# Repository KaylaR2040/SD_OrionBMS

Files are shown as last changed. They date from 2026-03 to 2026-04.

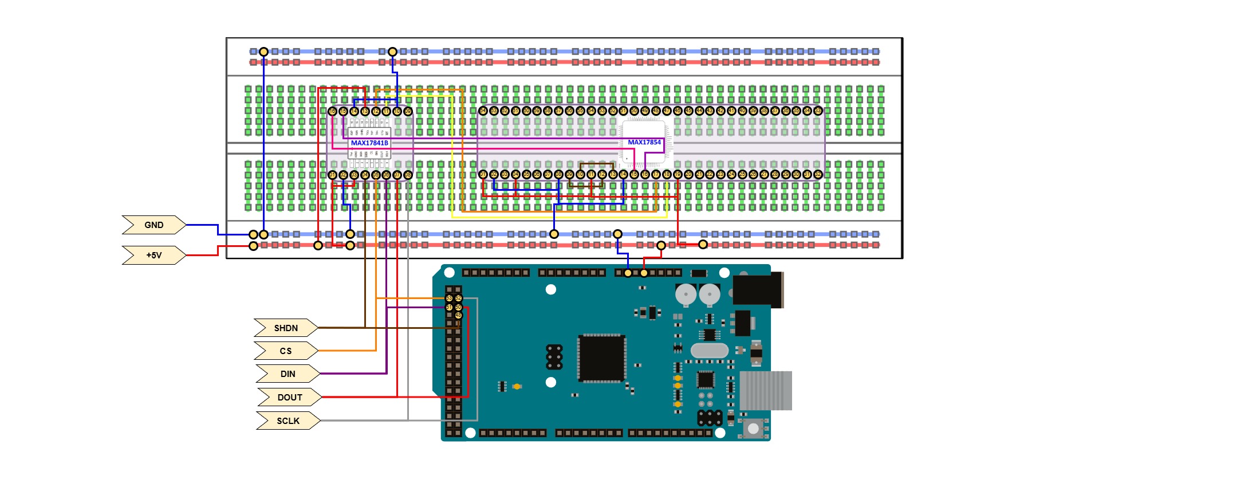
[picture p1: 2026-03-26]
Docs/SPI_ADC_BREADBOARD.jpg

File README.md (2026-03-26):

# EV Active Sensor Adapter

A compact, HV-aware sensing module for an FSAE EV accumulator. It acquires per-cell voltages and thermistor temperatures, validates each sample batch, and publishes telemetry on Classical CAN for the logger/BMS. The firmware uses an RTOS framework with timer-triggered ADC + DMA, deterministic validation/packetization, and an isolated CAN transceiver. The repository is structured so any developer can rebuild, verify, and extend the system quickly.

---

## Table of Contents
- [Project Purpose](#project-purpose)
- [Core Functionality](#core-functionality)
- [System Architecture](#system-architecture)
- [RTOS Design (Actors & IPC)](#rtos-design-actors--ipc)
- [Repository Structure](#repository-structure)
- [Build & Run](#build--run)
- [Configuration](#configuration)
- [Data & CAN](#data--can)
- [Documentation (Doxygen)](#documentation-doxygen)
- [File/Library Origins & Licenses](#filelibrary-origins--licenses)
- [Issue Tracking & Versioning](#issue-tracking--versioning)
- [Keywords / SEO](#keywords--seo)
- [Target Audience](#target-audience)
- [Roadmap](#roadmap)
- [Acknowledgments](#acknowledgments)

---

## Project Purpose
Design and validate a pass-through “active sensor adapter” that reads per-cell voltages and thermistors and relays them to the team’s logger/BMS over CAN. The goals are to minimize wiring and board count, meet the accumulator envelope and safety requirements, and keep the system straightforward to integrate and debug during scrutineering.

## Core Functionality
- **Acquisition:** Differential cell-tap sensing per segment; scaling to MCU ADC range (0–3.3 V) via analog front-end; thermistor sense and linearization.
- **Validation:** Range checks, monotonicity/slew checks, optional moving average/median filtering; configurable limits.
- **Publication:** Periodic CAN frames with per-cell voltages, temperatures, and health flags; heartbeat and diagnostics frames.
- **Timing:** ADC triggered by hardware timer; DMA → processing → CAN TX within fixed RTOS time budgets.
- **Safety & EMC:** Isolated CAN PHY; partitioned HV/LV domains; input protection and layout rules for creepage/clearance.

---

## System Architecture
**High level**
```
[Cell Taps & Thermistors] → [Analog Front-End] → [MCU ADC + DMA] 
    → [RTOS Tasks: Validate, Packetize] → [CAN Controller] → [Isolated CAN Transceiver] → [Logger / BMS]
```

**Major blocks**
- **Analog Front-End:** Differential measurement per cell segment; scale/offset to ADC domain; RC anti-alias/filtering; ESD/OVP where applicable.
- **MCU + Firmware:** ADC + DMA; timer-driven sampling; RTOS tasks for validation/packing; CAN driver; non-volatile config.
- **CAN Subsystem:** On-chip CAN controller (Classical CAN; 11/29-bit); isolated transceiver; configurable bitrate and filters.

---

## RTOS Design (Actors & IPC)
| Actor (Type) | Purpose | Period / Trigger | IPC / Resources |
|---|---|---|---|
| `adc_sampler` (ISR/DMA CB)| Kick conversions; DMA completion handling | Timer @ e.g., 100–200 Hz  | Queue → `validate_task` |
| `validate_task` (task) | Range/slew checks; filtering | On queue receive | Queue → `can_tx_task` |
| `can_tx_task` (task) | Pack frames; rate-limit; send via CAN | On queue / 10–50 Hz slots | CAN driver; TX mailbox |
| `diag_task` (task) | Heartbeat; error counters; self-tests | 1 Hz | CAN driver |
| `config_task` (task) | Apply params from NVM/debug console | On command | NVM / CLI / UART (optional)|

IPC: queues for sample batches, mutex for config access, event flags for errors/heartbeat, semaphore for CAN TX credit.  
RTOS: FreeRTOS or CMSIS-RTOS2 shim. The framework is present even if minimal features are used.

---

## Repository Structure
```
.
├─ firmware/
│  ├─ app/
│  │  ├─ main.c
│  │  ├─ tasks_can.c
│  │  ├─ tasks_validate.c
│  │  ├─ tasks_diag.c
│  │  └─ app_config.h
│  ├─ drivers/
│  │  ├─ adc_drv.c/.h
│  │  ├─ can_drv.c/.h
│  │  ├─ timer_drv.c/.h
│  │  └─ board_pins.h
│  ├─ rtos/
│  │  ├─ rtos_port.c/.h         # CMSIS-RTOS2 or FreeRTOS glue
│  │  └─ freertos/              # (if vendored; else via submodule)
│  ├─ utils/
│  │  ├─ filters.c/.h
│  │  ├─ crc.c/.h
│  │  └─ log.c/.h
│  └─ CMakeLists.txt / *.project (if CCS)
├─ hardware/
│  ├─ schematics/
│  └─ pcb/
├─ dbc/
│  └─ ev_active_sensor.dbc
├─ tools/
│  ├─ can_dump_example.py
│  └─ dbc_gen.py
├─ docs/
│  ├─ doxygen/
│  │  └─ Doxyfile
│  └─ images/
├─ LICENSE
└─ README.md
```

---

## Build & Run

You can recreate the system using one of the paths below. All code elements should build directly in GitHub CI and locally.

### Option A: TI Code Composer Studio (CCS)
1. Install CCS and the vendor SDK/driver pack for TMS320F23897xD.
2. `File → Import… → Existing CCS Project`, select `firmware/`.
3. Select the correct target and connection.
4. Build and flash. Use the “Release” profile for timing-accurate tests.

### Option B: CMake + ARM GCC (or vendor GCC)
```bash
cd firmware
cmake -B build -DCMAKE_TOOLCHAIN_FILE=toolchains/arm-none-eabi.cmake -DMCU=<TMS320F23897x>
cmake --build build -j
# Flash with preferred programmer, e.g.:
# openocd -f interface/<probe>.cfg -f target/TMS320F23897x.cfg -c "program build/firmware.elf verify reset exit"
```

### Bring-up checklist
- Confirm ADC reference and pin mapping in `board_pins.h` and `app_config.h`.
- Set CAN bitrate/filters in `app_config.h` (500 kbps, 1megps).
- Connect isolated CAN transceiver to the vehicle bus; verify TX/RX loopback on bench first.
- Start the logger; verify heartbeat and telemetry frames appear at the expected rates.

---

## Configuration
Edit `app_config.h` (or use CLI/UART if enabled):
- `SAMPLE_RATE_HZ`, `CAN_BITRATE`, `FRAME_PERIOD_MS`
- Channel enable masks; number of cells; thermistor Beta constants
- DBC frame IDs and scaling

---

## Data & CAN
- **CAN Type:** Classical CAN (11-bit or 29-bit).
- **Frames:**
  - `CELL_VOLTAGES_n`: packed per-cell voltages (scaled in mV)
  - `CELL_TEMPS_n`: packed temperatures (0.1 °C or °C)

---

## Documentation (Doxygen)
- In-code comments follow Doxygen style; functions link back to project requirements via `@req EV-REQ-###`.
- Generate docs locally:
  ```bash
  doxygen docs/doxygen/Doxyfile
  ```
- Publish: upload `docs/html/` via GitHub Pages or attach as a CI artifact.

---

## File/Library Origins & Licenses
- **Our code:** `firmware/app`, `firmware/utils`, and project glue — Apache-2.0 (see `LICENSE`).
- **RTOS:** FreeRTOS (MIT) via submodule or vendor package; see submodule `LICENSE`.
- **Drivers:** Either written in-house (Apache-2.0) or vendor HAL (vendor license). Each file header states origin and license.
- **DBC & tools:** Team-authored, Apache-2.0 unless otherwise noted.

> Every third-party directory includes a `NOTICE` with origin URL, version, and license.

---

## Issue Tracking & Versioning
- Use GitHub Issues for bugs/features. Each issue should include: owner, date, code version (git SHA), description, and resolution.
- Commits must include *what changed and why* in the message body.
- Releases are tagged (`vMAJOR.MINOR.PATCH`), with one marked **Final** for hand-off at semester end.

---

## Keywords / SEO
FSAE EV, battery monitoring, cell voltage sensing, thermistor sensing, differential measurement, ADC DMA, Classical CAN, isolated CAN transceiver, RTOS, FreeRTOS, CMSIS-RTOS2, embedded firmware, automotive EMC, accumulator.

## Target Audience
FSAE teams, embedded/firmware students, and engineers building HV-aware sensing for battery telemetry.

---

## Roadmap
- [ ] Bench characterization: ADC INL/DNL, noise, and filter step response
- [ ] Fault injection: wire-off, short, out-of-range, thermistor open/short
- [ ] CAN filter/ID finalization with logger/BMS DBC
- [ ] Production test mode & golden-frame generator
- [ ] CI: static analysis and unit tests for filters and validators

---

## Acknowledgments
Thanks to faculty mentors, the electrical subteam, and sponsors supporting test equipment and PCB fab.

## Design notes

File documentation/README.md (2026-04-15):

# SD Orion BMS Documentation

This folder is the maintainable documentation set for the STM32G474-based Orion thermistor and battery-monitor interface firmware in this repository.

Content is derived from active source (`src/`, `include/`, `platformio.ini`) and checked-in project docs/vendor references in `Docs/`.

## Who this is for

- New engineers bringing up a fresh board or MCU
- Firmware developers navigating architecture and modules
- Debug/operations engineers handling flashing, boot, logging, CAN, and battery-monitor issues

## What this documentation covers

- Fast onboarding and first flash
- Hardware setup and signal/pin mapping
- Firmware architecture and code map
- Communication behavior (USART2 logs, USART1 BQ transport, FDCAN)
- Troubleshooting, known issues, and bring-up recovery
- Chip inventory and board component references

## Start here

1. `getting_started.md`
2. `hardware_setup.md`
3. `pinout_and_signals.md`
4. `startup_and_flashing.md`

Then continue with:

- `system_overview.md`
- `firmware_overview.md`
- `code_map.md`
- `communication.md`

For debugging:

- `logging_and_leds.md`
- `troubleshooting.md`
- `known_issues_and_resolutions.md`
- `bringup_checklist.md`

Reference and component details:

- `reference/hardware_reference.md`
- `reference/firmware_reference.md`
- `reference/toolchain_and_programmer_reference.md`
- `reference/chip_inventory.md`

## Critical bring-up note

For this project, first-time MCU bring-up must include STM32CubeProgrammer option-byte review and reset/debug configuration before trusting normal flashing/debug behavior. See `startup_and_flashing.md`.

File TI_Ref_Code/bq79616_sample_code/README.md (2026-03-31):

# BQ79616-Q1 Sample Code for TMS570LS1224 (LAUNCH XL2)
This repository contains the BQ79616-Q1 sample code for the TMS570LS1224. This includes many useful functions that can be used for future development for the BQ79616-Q1.
## Pinout
CONNECTIONS BETWEEN BQ79616EVM AND LAUNCH XL2 (TMS570LS1224): 

* bq79616EVM J17 pin 1 (NC)     -> FLOAT
* bq79616EVM J17 pin 2 (NC)     -> FLOAT
* bq79616EVM J17 pin 3 (NFAULT) -> LAUNCH XL2 J4 pin 10 (PA0)
* bq79616EVM J17 pin 4 (NC)     -> FLOAT
* bq79616EVM J17 pin 5 (GND)    -> LAUNCH XL2 J3 pin 2  (GND)
* bq79616EVM J17 pin 6 (3V3)    -> LAUNCH XL2 J2 pin 1  (3V3)
* bq79616EVM J17 pin 7 (RX)     -> LAUNCH XL2 J2 pin 4  (UATX)
* bq79616EVM J17 pin 8 (TX)     -> LAUNCH XL2 J2 pin 3  (UARX)
* bq79616EVM J17 pin 9 (NC)     -> FLOAT
* bq79616EVM J17 pin 10 (NC)    -> FLOAT

RELEVANT MODIFIED FILES:

* bq79616.h        must change TOTALBOARDS and MAXBYTES here for code to function
* bq79616.c        contains all relevant functions used in the sample code
* notification.c   sets UART_RX_RDY and RTI_TIMEOUT when their respective interrupts happen
* .dil/.hcg        used for generating the basic TMS570LS1224 code files, can be used to make changes to the microcontroller

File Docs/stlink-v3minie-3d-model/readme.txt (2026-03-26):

******************************************************************************
* @file    readme.txt
* @author  GPAM Application Team
* @version 1.0
* @date    28-March-2025
* @brief   STLINK-V3MINIE 3D model
******************************************************************************
* COPYRIGHT(c) 2025 STMicroelectronics
*
* The Open Platform License Agreement (“Agreement”) is a binding legal contract
* between you ("You") and STMicroelectronics International N.V. (“ST”), a
* company incorporated under the laws of the Netherlands acting for the purpose
* of this Agreement through its Swiss branch 39, Chemin du Champ des Filles,
* 1228 Plan-les-Ouates, Geneva, Switzerland.
*
* By using the enclosed reference designs, schematics, PC board layouts, and
* documentation, in hardcopy or CAD tool file format (collectively, the
* “Reference Material”), You are agreeing to be bound by the terms and
* conditions of this Agreement. Do not use the Reference Material until You
* have read and agreed to this Agreement terms and conditions. The use of
* the Reference Material automatically implies the acceptance of the Agreement
* terms and conditions.
*
* The complete Open Platform License Agreement can be found on www.st.com/opla.
******************************************************************************

========================
* 1.0 - 28-March-2025
========================
    + First official release.
  
******************* (C) COPYRIGHT 2025 STMicroelectronics *****END OF FILE

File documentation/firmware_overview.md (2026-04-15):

# Firmware Overview

## Runtime architecture

The firmware is organized as a simple service loop with timer-driven scheduling flags:

- Main loop (`src/main.c`):
  - `Therm_ServiceTask()`
  - `CAN_ServiceTask()`
  - `Volt_ServiceTask()`

- System startup (`src/init.c`):
  - HAL/clocks/GPIO/LED
  - UART init (STLINK + BQ)
  - ADC + CAN + timers
  - blocking BQ bring-up state gate

## Startup sequence

`System_AppInit()` executes this order:

1. `HAL_Init()`
2. `SystemClock_Config()`
3. `LED_Init()`
4. `clocks_configure_all()`
5. `UART_Stlink_Init()` (USART2)
6. `UART_BQ79616_Init()` (USART1)
7. `Therm_App_Init()`
8. `CAN_App_Init(1000 kbps)`
9. `Timers_Init()`
10. `Volt_RunBlockingStartup()`
11. Release CAN scheduling based on BQ state

## Major modules and responsibilities

- `src/therm.c`: ADC1 channel sampling, thermistor snapshot logging
- `src/thermistor_table.c`: ADC-to-temperature conversion
- `src/can.c`: FDCAN init/transport and service entry
- `src/can_messages.c`: message encoding, fault handling, transmission scheduling hooks
- `src/bq79616.c`: wake, keep-alive, fault polling, cell reads
- `src/volt.c`: BQ state machine wrapper and degraded-mode behavior
- `src/timer.c`: TIM6/TIM7 scheduling and staggered log flags
- `src/uart.c`: logging layer and BQ UART transport handles

## Firmware data flow

1. Therm ADC values captured into `g_can_ctx.thermistors`.
2. Temperature/fault cache computed.
3. BQ task updates external voltage buffer into `g_can_ctx.voltages`.
4. CAN task packages and sends periodic frames.
5. UART logging and LEDs expose state transitions/failures.

## Init/loop/driver relationships

- Initialization is centralized in `System_AppInit()`.
- Driver and protocol code stay in dedicated modules.
- ISRs stay short; periodic work is done in service tasks in non-ISR context.

See also:

- `code_map.md`
- `communication.md`
- `diagrams/startup_flowchart.md`

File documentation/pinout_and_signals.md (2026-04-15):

# Pinout and Signals

This is the consolidated pin and interface map for bring-up/debug, derived from active code first and then cross-checked against existing project notes.

## Source-of-truth priority

1. Active code in `src/` and `include/`
2. Board/vendor docs in `Docs/`
3. Older notes only when they agree with code

## MCU pin map used by current firmware

### UART

| Function | Peripheral | MCU Pin | Source |
|---|---|---|---|
| Log TX | USART2 TX | `PA2` | `src/uart.c`, `src/stm32g4xx_hal_msp.c` |
| Log RX | USART2 RX | `PA3` | `src/uart.c`, `src/stm32g4xx_hal_msp.c` |
| BQ TX | USART1 TX | `PC4` | `src/uart.c`, `src/stm32g4xx_hal_msp.c` |
| BQ RX | USART1 RX | `PC5` | `src/uart.c`, `src/stm32g4xx_hal_msp.c` |

### CAN

| Function | Peripheral | MCU Pin | Source |
|---|---|---|---|
| CAN RX | FDCAN1 RX | `PA11` | `src/stm32g4xx_hal_msp.c` |
| CAN TX | FDCAN1 TX | `PA12` | `src/stm32g4xx_hal_msp.c` |

### ADC thermistor channels

| Therm Channel | ADC Channel | MCU Pin | Source |
|---|---|---|---|
| 1 | ADC1_IN1 | `PA0` | `src/therm.c` |
| 2 | ADC1_IN2 | `PA1` | `src/therm.c` |
| 3 | ADC1_IN11 | `PB12` | `src/therm.c` |
| 4 | ADC1_IN14 | `PB11` | `src/therm.c` |
| 5 | ADC1_IN5 | `PB14` | `src/therm.c` |
| 6 | ADC1_IN6 | `PC0` | `src/therm.c` |
| 7 | ADC1_IN7 | `PC1` | `src/therm.c` |
| 8 | ADC1_IN8 | `PC2` | `src/therm.c` |
| 9 | ADC1_IN9 | `PC3` | `src/therm.c` |
| 10 | ADC1_IN15 | `PB0` | `src/therm.c` |

### LEDs

| LED | MCU Pin | Source |
|---|---|---|
| LED1 | `PA9` | `include/main.h` |
| LED2 | `PA8` | `include/main.h` |
| LED3 | `PC9` | `include/main.h` |

## SWD / programming signals

The firmware docs assume standard SWD wiring is present and stable:

- SWDIO
- SWCLK
- NRST
- GND
- VREF

Project bring-up requirement:

- Use **NRST Level 3** in programmer setup for reliable flashing/debug behavior in this project.

See `startup_and_flashing.md`.

## Known pinout note conflict in older docs

`Docs/PINOUT.md` contains a logging UART mapping that references LPUART1/AF12 on `PA2/PA3`, while active code configures USART2/AF7 for logging. Current firmware source (`src/uart.c`, `src/stm32g4xx_hal_msp.c`) is the authoritative mapping.

## Quick bench validation

1. Confirm UART logs at `115200` over STLINK VCP.
2. Confirm CAN traffic on FDCAN1 (`PA11`/`PA12`).
3. Confirm therm channels produce changing ADC values in logs.
4. Confirm BQ transport path uses `PC4`/`PC5` at `1000000` baud.

See also:

- `hardware_setup.md`
- `communication.md`
- `logging_and_leds.md`
- `reference/chip_inventory.md`

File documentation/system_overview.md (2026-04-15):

# System Overview

## What this project does

This firmware runs on STM32G474 and publishes battery/thermal telemetry to CAN. It:

- Samples up to 10 thermistor channels on MCU ADC1
- Talks to a BQ79616 battery monitor chain over USART1
- Publishes Orion-style thermistor and external-voltage CAN frames over FDCAN1
- Emits debug/status logs over STLINK VCP (USART2)

## Main system components

- STM32G474 firmware core (`src/main.c`, `src/init.c`)
- Thermistor acquisition path (`src/therm.c`, `src/thermistor_table.c`)
- BQ79616 interface path (`src/bq79616.c`, `src/volt.c`)
- CAN transport and message packing (`src/can.c`, `src/can_messages.c`)
- Timing/scheduling (`src/timer.c`)

## High-level data flow

1. ADC samples thermistors.
2. Temperatures/fault masks are computed.
3. BQ path keeps comms alive and reads external cell voltages.
4. CAN scheduler transmits claim, BMS summary, general thermistor frames, and external-voltage segments.
5. Logs and LEDs expose runtime state.

See diagram: `diagrams/system_block_diagram.md`

## Startup/connection overview

- `System_AppInit()` initializes clocks, GPIO, UARTs, ADC, CAN, and timers.
- Startup blocks in BQ bring-up (`Volt_RunBlockingStartup()`), then CAN scheduling is released.
- If BQ fails, thermistor/CAN path still runs in degraded fault-reporting mode.

See diagram: `diagrams/startup_flowchart.md`

## Inputs and outputs

Inputs:

- Thermistor analog channels (ADC1)
- BQ UART response data
- Power/reset/debug configuration state

Outputs:

- UART logs on USART2 at 115200
- CAN frames on FDCAN1 at 1 Mbps default
- LED status indication for subsystem failures

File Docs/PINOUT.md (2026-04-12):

# Pin Assignments - STM32G474RET6
> Last Updated 4/12/26

Single consolidated map, grouped by peripheral/function. AF values match the HAL MSP setup in `src/stm32g4xx_hal_msp.c`.

| Group | Signal / Use | Pin | Pin # | AF / Mode | External Connection / Notes |
|---|---|---|---|---|---|
| UART | USART1 TX (BQ79616) | PC4 | 24 | AF7 USART1 | Connect to BQ79616-Q1 RX (Pin 52) |
| UART | USART1 RX (BQ79616) | PC5 | 25 | AF7 USART1 | Connect to BQ79616-Q1 TX (Pin 53) |
| UART | LPUART1 TX (logging) | PA2 | 14 | AF12 LPUART1 | Connect to ST-LINK `T_VCP_TX` (USB logging) |
| UART | LPUART1 RX (logging) | PA3 | 17 | AF12 LPUART1 | Connect to ST-LINK `T_VCP_RX` (USB logging) |
| CAN | FDCAN1 RX | PA11 | 46 | AF9 FDCAN1 | 1 Mbps default |
| CAN | FDCAN1 TX | PA12 | 47 | AF9 FDCAN1 | 1 Mbps default |
| SPI | SPI1 SCK | PA5 | 19 | AF5 SPI1 | MAX17841B / ASCI |
| SPI | SPI1 MISO | PA6 | 20 | AF5 SPI1 |  |
| SPI | SPI1 MOSI | PA7 | 21 | AF5 SPI1 |  |
| SPI | SPI1 CS (software) | PA4 | 18 | GPIO output | MAX17841B chip select (manual) |
| LED | LED1 | PA9 | 43 | GPIO output | Active high |
| LED | LED2 | PA8 | 42 | GPIO output | Active high |
| LED | LED3 | PC9 | 41 | GPIO output | Active high |
| GPIO | Spare | PC6 | 37 | GPIO | Unused |
| GPIO | Spare / analog header | PB15 | 36 | GPIO/Analog | Unused |
| GPIO | Spare / analog header | PB13 | 34 | GPIO/Analog | Unused |
| ADC1 | IN1 (Thermistor 1) | PA0 | 12 | Analog | ADC_CHANNEL_1 |
| ADC1 | IN2 (Thermistor 2) | PA1 | 13 | Analog | ADC_CHANNEL_2 |
| ADC1 | IN11 (Thermistor 3) | PB12 | 35 | Analog | ADC_CHANNEL_11 |
| ADC1 | IN14 (Thermistor 4) | PB11 | 33 | Analog | ADC_CHANNEL_14 |
| ADC1 | IN5 (Thermistor 5) | PB14 | 36 | Analog | ADC_CHANNEL_5 |
| ADC1 | IN6 (Thermistor 6) | PC0 | 8 | Analog | ADC_CHANNEL_6 |
| ADC1 | IN7 (Thermistor 7) | PC1 | 9 | Analog | ADC_CHANNEL_7 |
| ADC1 | IN8 (Thermistor 8) | PC2 | 10 | Analog | ADC_CHANNEL_8 |
| ADC1 | IN9 (Thermistor 9) | PC3 | 11 | Analog | ADC_CHANNEL_9 |
| ADC1 | IN15 (Thermistor 10) | PB0 | 23 | Analog | ADC_CHANNEL_15 |

## Notes
- BQ79616 runs on USART1 (PC4/PC5). Logging defaults to LPUART1 (PA2/PA3) to keep pins separated.
- PA4 is the software CS for MAX17841B (SPI1).
- All LEDs are active high; LED5 is the fault indicator.
- No DMA is used; UARTs/SPI are blocking for bring-up.
- BQ79616 datasheet reference: https://www.ti.com/lit/ds/symlink/bq79612-q1.pdf

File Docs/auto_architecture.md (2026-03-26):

# EV Active Sensor Adapter - Firmware System Architecture

## System Overview

```mermaid
flowchart LR
    subgraph SCHED["Execution and Scheduling"]
        direction TB
        BOOT["Boot and Init"]
        TICK["1ms Timebase"]
        LOOP["Main Service Loop"]
        BOOT --> TICK --> LOOP
    end

    subgraph VOLT["Voltage Lane"]
        direction TB
        V_IN["Cell Taps x14"]
        V_AFE["Analog Front-End"]
        V_ADC["External HV ADC"]
        V_TRS["UART TO SPI TRANSLATOR"]
        V_SPI["SPI Driver"]
        V_PROC["Voltage Processing"]
        V_IN --> V_AFE --> V_ADC <--> V_TRS <-->V_SPI --> V_PROC
    end

    subgraph TEMP["Temperature Lane"]
        direction TB
        T_IN["Thermistors x10"]
        T_ADC["STM32 ADC"]
        T_CONV["Lookup Table Conversion"]
        T_PROC["Temp Processing"]
        T_IN --> T_ADC --> T_CONV --> T_PROC
    end

    subgraph MODEL["Data Model"]
        direction TB
        BUF["Measurement Buffers"]
        META["Timestamps"]
        FAULTS["Fault State"]
        BUF --- META
        META --- FAULTS
    end

    subgraph FRAME["Message Assembly"]
        direction TB
        PACK["Frame Builder"]
        CRC["Checksum"]
        RATE["Rate Control"]
        PACK --> CRC --> RATE
    end

    subgraph CANNET["CAN Transport"]
        direction TB
        CAN_API["CAN API"]
        CAN_HAL["FDCAN HAL"]
        BUS["CAN Bus"]
        CAN_API --> CAN_HAL --> BUS
        BUS --> CAN_HAL --> CAN_API
    end

    subgraph DBG["Debug Interface"]
        direction TB
        LEDS["Status LEDs"]
        UART["UART Console"]
    end

    subgraph CONSUMERS["External Consumers"]
        direction TB
        BMS["Orion BMS"]
        LOGGER["Data Logger"]
    end

    LOOP --> V_SPI
    LOOP --> T_ADC
    V_PROC --> BUF
    T_PROC --> BUF
    BUF --> PACK
    META --> PACK
    FAULTS --> PACK
    RATE --> CAN_API
    CAN_API --> LEDS
    CAN_API --> UART
    FAULTS --> LEDS
    FAULTS --> UART
    BUS --> BMS
    BUS --> LOGGER
```

## Timing Constraints

```mermaid
flowchart TB
    subgraph TIMING["Message Timing Requirements"]
        direction LR
        T1["J1939 Address Claim"]
        T2["BMS Broadcast"]
        T3["General Broadcast"]
        T4["ADC Sampling"]
        T5["SPI Polling"]
    end

    T1 --- PERIOD1["200 ms period"]
    T2 --- PERIOD2["100 ms period"]
    T3 --- PERIOD3["100 ms period, round-robin"]
    T4 --- PERIOD4["Configurable, typical 100 ms"]
    T5 --- PERIOD5["Configurable, typical 200 ms"]
```

## Data Flow Detail

```mermaid
flowchart TB
    subgraph ADC_ACQUIRE["ADC Acquisition"]
        ADC_TASK["ADC_ServiceTask()"]
        ADC_SAMPLE["Sample 10 channels"]
        ADC_RAW["Raw ADC counts 0-4095"]
    end

    subgraph CONVERT["Temperature Conversion"]
        LOOKUP["Lookup Table"]
        CLAMP["Clamp to int8 range"]
        TEMPS["s_temps array"]
    end

    subgraph ENCODE["CAN Encoding"]
        BMS_ENC["EncodeBMSBroadcast()"]
        GEN_ENC["EncodeGeneralBroadcast()"]
        PAYLOAD["8-byte payload"]
    end

    subgraph TRANSMIT["CAN Transmit"]
        SEND_EXT["CAN_Comm_SendExt()"]
        FDCAN["FDCAN Peripheral"]
        WIRE["Physical Bus"]
    end

    ADC_TASK --> ADC_SAMPLE --> ADC_RAW
    ADC_RAW --> LOOKUP --> CLAMP --> TEMPS
    TEMPS --> BMS_ENC --> PAYLOAD
    TEMPS --> GEN_ENC --> PAYLOAD
    PAYLOAD --> SEND_EXT --> FDCAN --> WIRE
```

## Module Responsibilities

| Module | File | Purpose | Timing |
|---|---|---|---|
| Main | main.c | Init and main loop | Continuous |
| ADC | adc.c | Sample thermistor channels | Periodic |
| SPI | spi.c | Poll MAX17841 for cell data | Periodic |
| Thermistor | thermistor_table.c | ADC to temperature lookup | On demand |
| CAN Messages | can_messages.c | Encode BMS and General frames | On demand |
| CAN Core | can.c | FDCAN init, send, receive | Periodic |
| Timer | timer.c | HAL_GetTick based timing | 1 ms tick |
| Log | log.c | UART debug output | On demand |
| LED | led.c | Status indication | Periodic |
| Error | error_handling.c | Fault handling | On event |

## CAN Message Schedule

| Message | CAN ID | Period | Payload |
|---|---|---|---|
| J1939 Address Claim | 0x18EEFF80 | 200 ms | 8 bytes fixed |
| BMS Broadcast | 0x1839F380 | 100 ms | Module summary |
| General Broadcast | 0x183BF380 | 100 ms | Single thermistor, round-robin |

## Temperature Data Path

```mermaid
flowchart LR
    THERM["Thermistor"] --> DIVIDER["Voltage Divider"] --> PIN["ADC Pin"]
    PIN --> SAMPLE["ADC Sample"] --> COUNT["0-4095 count"]
    COUNT --> TABLE["Lookup Table"] --> SIGNED["int8_t temp"]
    SIGNED --> CAST["cast to uint8_t"] --> WIRE["CAN payload byte"]
    WIRE --> BMS["Orion BMS interprets as int8_t"]
```

## Initialization Sequence

```mermaid
flowchart TB
    START["Power On"] --> HAL["HAL_Init()"]
    HAL --> CLK["SystemClock_Config()"]
    CLK --> GPIO["GPIO_App_Init()"]
    GPIO --> UART["UART_Log_Init()"]
    UART --> ADC["ADC_App_Init()"]
    ADC --> SPI["SPI_App_Init()"]
    SPI --> CAN["CAN_App_Init()"]
    CAN --> LED["LED_Init()"]
    LED --> LOOP["Enter Main Loop"]
```

## Main Loop Execution

```mermaid
flowchart TB
    LOOP["Main Loop Start"] --> CHECK_ADC{"ADC period elapsed?"}
    CHECK_ADC -- yes --> RUN_ADC["ADC_ServiceTask()"]
    CHECK_ADC -- no --> CHECK_SPI
    RUN_ADC --> CHECK_SPI{"SPI period elapsed?"}
    CHECK_SPI -- yes --> RUN_SPI["SPI_ServiceTask()"]
    CHECK_SPI -- no --> CHECK_CAN
    RUN_SPI --> CHECK_CAN{"CAN period elapsed?"}
    CHECK_CAN -- yes --> RUN_CAN["CAN_ServiceTask()"]
    CHECK_CAN -- no --> LOOP
    RUN_CAN --> LOOP
```

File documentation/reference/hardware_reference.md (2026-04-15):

# Hardware Reference

Compact hardware facts extracted from active source and checked-in documentation.

## MCU and firmware target context

- Target MCU family: STM32G474 (`platformio.ini`, `STM32G474xx`)
- PlatformIO board env: `nucleo_g474re`
- Firmware uses HAL and selected LL modules

## Active pin/interface mappings from code

- UART logging: USART2 `PA2` TX / `PA3` RX (`src/uart.c`, `src/stm32g4xx_hal_msp.c`)
- BQ UART transport: USART1 `PC4` TX / `PC5` RX (`src/uart.c`, `src/stm32g4xx_hal_msp.c`)
- CAN: FDCAN1 `PA11` RX / `PA12` TX (`src/stm32g4xx_hal_msp.c`)
- Thermistor ADC channels (10): `PA0`, `PA1`, `PB12`, `PB11`, `PB14`, `PC0`, `PC1`, `PC2`, `PC3`, `PB0` (`src/therm.c`)
- LEDs: `PA9`, `PA8`, `PC9` (`include/main.h`)

For full signal tables, use `../pinout_and_signals.md`.

## Power and probe notes

- STLINK-V3MINIE supports debug/program and VCP.
- Checked-in ST docs (`Docs/um2910-*.pdf`) state STLINK-V3MINIE does not provide target application power.
- Use external target power for bring-up and runtime testing.

## Boot/reset bring-up notes (project)

- First-time bring-up requires option-byte review in CubeProgrammer.
- Project requires NRST Level 3 during setup/flashing for reliable behavior.
- Treat NRST Level 3 as project-specific unless validated otherwise on your hardware revision.

## Chip/component scope notes

- Active firmware path clearly uses STM32G474 + BQ79616.
- Additional component docs (for example ISO1050, MAX17841/MAX17854) are present in `Docs/` and should be verified against actual board population/BOM before use.

For complete component status, use `chip_inventory.md`.

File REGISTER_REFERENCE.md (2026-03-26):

/*
 * ===========================================================================
 * BQ79616 WAKE-UP SEQUENCE: REGISTER GUIDE
 * ===========================================================================
 *
 * This explains which registers are involved in waking up the BQ79616 from
 * SHUTDOWN mode and what they do.
 *
 * ===========================================================================
 * OVERVIEW OF DEVICE POWER STATES
 * ===========================================================================
 *
 * The BQ79616 has two main power modes:
 *
 * 1. SHUTDOWN MODE (Default after power-up)
 *    ├─ Minimal current draw
 *    ├─ No analog power to battery monitoring circuits
 *    ├─ No UART communications possible
 *    └─ Woken by: Two TX-low pulses on UART RXD line
 *
 * 2. ACTIVE MODE (After successful wake)
 *    ├─ Full power to analog circuits
 *    ├─ UART communication enabled
 *    ├─ Battery monitoring active
 *    └─ Returns to SHUTDOWN after timeout (if enabled)
 *
 *
 * ===========================================================================
 * REGISTER: CONTROL1 (Address 0x0001)
 * ===========================================================================
 *
 * This is the KEY register for wake control!
 *
 * BIT LAYOUT:
 * ───────────────────────────────────────────────────────────────────
 * BIT#  | NAME              | PURPOSE
 * ───────────────────────────────────────────────────────────────────
 *  7-6  | (reserved)        | Must be 0
 *  5    | SEND_WAKE         | ← THIS WAKES STACKED DEVICES
 *  4-2  | (reserved)        | Must be 0
 *  1-0  | (reserved)        | Must be 0
 * ───────────────────────────────────────────────────────────────────
 *
 * SEND_WAKE BIT (Bit 5):
 * ├─ Write 1: Device sends wake signal down the stack
 * ├─ Write 0: Normal operation
 * └─ Used in: bq79616_stack_single_init()
 *
 * YOUR CODE SENDS:
 * ────────────────
 *   uint8_t control1 = BQ_CONTROL1_SEND_WAKE_MASK;  // 0x20 = 0b0010_0000
 *   bq79616_write(0u, BQ_REG_CONTROL1_ADDR, &control1, 1u);
 *
 * This sets SEND_WAKE=1 which tells the bridge to pass the wake signal to
 * any stacked BQ79616 devices below it.
 *
 *
 * ===========================================================================
 * REGISTER: STATUS (Address 0x0000) - READ ONLY
 * ===========================================================================
 *
 * This tells you what mode the device is currently in.
 *
 * BIT LAYOUT (typical):
 * ─────────────────────────────────────────────────────
 * BIT#  | NAME                    | MEANING
 * ─────────────────────────────────────────────────────
 *  7    | No Cell Detected        | If 1: No cells detected
 *  6    | Cell Balance Mode       | If 1: Cell balancing active
 *  5    | Thermistor Mode         | If 1: Thermistor connected
 *  4    | ACTIVE                  | If 1: Device is ACTIVE ← CHECK THIS
 *  3    | (other)                 |
 *  2    | (other)                 |
 *  1    | (other)                 |
 *  0    | (other)                 |
 * ─────────────────────────────────────────────────────
 *
 * ⚠️  NOTE: Bit definitions vary by BQ79616 revision!
 *    Consult your specific datasheet for exact STATUS layout.
 *
 * TO CHECK IF DEVICE IS ACTIVE:
 * ─────────────────────────────
 *   uint8_t status = 0;
 *   bq79616_read(0u, 0x0000u, &status, 1u);
 *   
 *   if (status & 0x10) {  // Check bit 4 (example - verify your datasheet!)
 *       // Device is ACTIVE - analog power should be ON
 *       LOG_INFO("SUCCESS: Device is ACTIVE, analog power enabled");
 *   } else {
 *       // Device is still SHUTDOWN - wake sequence failed
 *       LOG_ERROR("FAIL: Device is SHUTDOWN, analog power OFF");
 *       LOG_ERROR("Status register: 0x%02X", status);
 *   }
 *
 *
 * ===========================================================================
 * INITIALIZATION SEQUENCE (Your Code Flow)
 * ===========================================================================
 *
 * in main.c:
 *
 *   // Step 1: Apply the two TX-low wake pulses
 *   // This wakes the device FROM SHUTDOWN TO ACTIVE
 *   BQ_WakeSequence(1u);
 *     └─ Generates two 2.75 ms TX-low pulses
 *     └─ Sends CONTROL1[SEND_WAKE]=1 via UART
 *     └─ Waits for propagation
 *
 *   // Step 2: Perform stack initialization  
 *   // This configures the device for operation
 *   bq79616_stack_single_init();
 *     └─ Write CONTROL1 = 0x20 (SEND_WAKE)
 *     └─ Enable auto-addressing (CONTROL1 = 0x01)
 *     └─ Set device address (DIR0 = 0x00)
 *     └─ Set stack configuration (COMM_CTRL = 0x03)
 *
 *
 * ===========================================================================
 * REGISTER: COMM_CTRL (Address 0x0003)
 * ===========================================================================
 *
 * Configures how the device communicates in the stack.
 *
 * BIT LAYOUT:
 * ────────────────────────────────────────────────────
 * BIT#  | NAME                    | PURPOSE
 * ────────────────────────────────────────────────────
 *  7-4  | (reserved)              | Must be 0
 *  3    | STACK_MODE              | If 1: Stack mode enabled
 *  2    | (reserved)              |
 *  1    | TOP_OF_STACK            | If 1: This device is top of stack
 *  0    | (reserved)              |
 * ────────────────────────────────────────────────────
 *
 * YOUR CODE SENDS:
 * ───────────────
 *   uint8_t control = 0x03;  // Binary: 0b0000_0011
 *   bq79616_write(0u, BQ_REG_COMM_CTRL, &control, 1u);
 *
 * This sets:
 *   - STACK_MODE = 1 (bit 3 set via 0x08, but you're writing 0x03...)
 *   - TOP_OF_STACK = 1 (bit 1 set via 0x02)
 *
 * ⚠️  NOTE: 0x03 may not be correct! Check datasheet for proper COMM_CTRL.
 *    Verify what bits actually need to be set for your specific BQ79616.
 *
 *
 * ===========================================================================
 * REGISTER: DIR0 (Address 0x0002)
 * ===========================================================================
 *
 * Device Identification Register - sets the device address in the stack.
 *
 * BIT LAYOUT:
 * ────────────────────────────────────────────────────
 * BIT#  | NAME                    | PURPOSE
 * ────────────────────────────────────────────────────
 *  7-6  | (reserved)              | Must be 0
 *  5-0  | DEVICE_ADDRESS          | Sets address (0-63 typical)
 * ────────────────────────────────────────────────────
 *
 * YOUR CODE SENDS:
 * ───────────────
 *   uint8_t addr = 0x00;
 *   bq79616_write(0u, BQ_REG_DIR0_ADDR, &addr, 1u);
 *
 * This sets the device address to 0x00.
 *
 * IMPORTANT for stacking:
 * ├─ Each device in a stack needs a unique address
 * ├─ Auto-addressing can assign these automatically
 * └─ Master device is usually address 0x00
 *
 *
 * ===========================================================================
 * DEBUGGING: REGISTER READ-BACK
 * ===========================================================================
 *
 * After wake sequence completes, verify register contents:
 *
 *    // Check STATUS
 *    uint8_t status = 0;
 *    bq79616_read(0u, 0x0000u, &status, 1u);
 *    LOG_INFO("STATUS: 0x%02X (expect ACTIVE bit set)", status);
 *    
 *    // Check CONTROL1
 *    uint8_t ctrl1 = 0;
 *    bq79616_read(0u, 0x0001u, &ctrl1, 1u);
 *    LOG_INFO("CONTROL1: 0x%02X (expect 0x20 after wake)", ctrl1);
 *    
 *    // Check COMM_CTRL
 *    uint8_t comm = 0;
 *    bq79616_read(0u, 0x0003u, &comm, 1u);
 *    LOG_INFO("COMM_CTRL: 0x%02X", comm);
 *    
 *    // Check DIR0 (address)
 *    uint8_t addr = 0;
 *    bq79616_read(0u, 0x0002u, &addr, 1u);
 *    LOG_INFO("DIR0: 0x%02X (expect 0x00)", addr);
 *
 * If reads succeed but STATUS doesn't show ACTIVE:
 *   → Device woke temporarily but fell back to SHUTDOWN
 *   → May need longer wait after wake, or additional configuration
 *   → Check BQ79616 datasheet for idle timeout settings
 *
 * If reads fail (CRC errors, no response):
 *   → Device is NOT responding to UART
 *   → Wake pulses likely didn't work
 *   → Go back to oscilloscope verification
 *
 *
 * ===========================================================================
 * REGISTER ADDRESSES REFERENCE
 * ===========================================================================
 *
 * Address  | Register Name              | R/W | Purpose
 * ---------|----------------------------|-----|----------------------------------
 * 0x0000   | STATUS                     | R   | Device status (ACTIVE bit, etc)
 * 0x0001   | CONTROL1                   | R/W | SEND_WAKE, wake configuration
 * 0x0002   | DIR0                       | R/W | Device address in stack
 * 0x0003   | COMM_CTRL                  | R/W | Stack mode, top-of-stack flag
 * 0x0004   | (depends on revision)      | -   | -
 * ...      | (consult datasheet)        | -   | -
 * 0x0080   | OTP_ECC_DATAIN1            | R   | OTP/ECC test register
 * 
 * ⚠️  Register layout varies by BQ79616 revision!
 *    Always consult the specific datasheet for your part number.
 *
 * ===========================================================================
 */

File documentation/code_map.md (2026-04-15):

# Code Map

This file is a navigation map to the current repository layout and the modules you usually touch first.

## Top-level layout (current)

- `src/` - firmware implementation
- `include/` - headers and shared APIs
- `Docs/` - legacy docs, vendor PDFs, hardware references
- `Other/` - logs and analysis scripts
- `platformio.ini` - build target, upload protocol, monitor speed

## Important source files

| Topic | Where to look |
|---|---|
| Main / entry point | `src/main.c` |
| System init / startup order | `src/init.c` |
| Clock setup | `src/init.c`, `src/clocks.c` |
| Hardware MSP pin setup | `src/stm32g4xx_hal_msp.c` |
| UART (logs + BQ transport) | `src/uart.c`, `include/uart.h` |
| CAN transport | `src/can.c`, `include/can.h` |
| CAN message encoding | `src/can_messages.c`, `include/can_messages.h` |
| ADC thermistor sampling | `src/therm.c`, `include/therm.h` |
| Thermistor conversion table | `src/thermistor_table.c` |
| Battery monitor interface | `src/bq79616.c`, `src/volt.c`, `include/bq79616.h`, `include/volt.h` |
| Logging macros | `include/uart.h` (`LOG_INFO/WARN/ERROR/DEBUG`) |
| LED control | `src/led.c`, `include/led.h` |
| Error handling | `src/error_handling.c`, `include/error_handling.h` |
| Timer scheduling/flags | `src/timer.c`, `include/timer.h` |

## Where to look for bring-up/debug topics

- Pin and signal mapping: `pinout_and_signals.md`
- Chip/component context: `reference/chip_inventory.md`
- CAN timing issue history: `Docs/CAN_TIMING_ISSUE_AND_FIX.md`
- BQ wake/startup behavior: `src/bq79616.c`, `include/bq79616.h`, `QUICK_START_GUIDE.md`, `REGISTER_REFERENCE.md`
- Captured CAN logs: `Other/can_log.txt`, `Other/can_diag_campaign_20260412_234404.log`

## Notes on older docs

Some root and `Docs/` markdown files describe older architectures. Treat active code under `src/` and `include/` as source of truth first.

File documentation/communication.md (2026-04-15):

# Communication

This project currently uses three active communication paths: UART logs, UART battery-monitor transport, and CAN.

## Communication interfaces in use

| Interface | Role | Firmware endpoints | Key settings |
|---|---|---|---|
| USART2 (STLINK VCP) | Console/log output | `UART_Stlink_Init`, `Log_Printf` | 115200, 8N1 |
| USART1 (BQ transport) | BQ79616 protocol path | `UART_BQ79616_Init`, `bq79616_*` | 1000000, 8N1 |
| FDCAN1 | Telemetry output to BMS/logger | `CAN_Comm_SendExt`, `CAN_SendMessages` | 1 Mbps nominal default |

## CAN frame set (current)

| Frame | ID | Typical cadence | Source |
|---|---|---|---|
| J1939 claim | `0x18EEFF80` | 200 ms | `CAN_EncodeJ1939ClaimForModule` |
| BMS therm summary | `0x1839F380` | 100 ms | `CAN_EncodeBmsForCache` |
| General therm round-robin | `0x1838F380` | 100 ms | `CAN_EncodeGeneralForCache` |
| External voltage segments | `0x18FF3000` to `0x18FF3003` | scheduled event | `CAN_EncodeExternalADCVoltage` |

## Data/message path

1. ADC thermistor values are sampled and converted.
2. Fault and thermal summary are computed.
3. BQ service reads cell voltages and updates external-voltage payload source.
4. TIM7 flags trigger message scheduling in `CAN_SendMessages()`.
5. FDCAN TX queue sends extended IDs; drops are rate-limited in logs.

See diagram: `diagrams/communication_flowchart.md`

## Hardware-side communication notes

- UART log path and BQ UART are separate and independently configured.
- If BQ path fails, CAN still runs in degraded fault-reporting mode.
- CAN pin mapping is `PA11` RX / `PA12` TX in MSP init.
- `Docs/iso1050.pdf` is present as CAN transceiver reference material; verify actual transceiver population and polarity against your board schematic/BOM before assuming hardware behavior.

## Common checks when communication fails

- No logs: verify USART2 VCP path and terminal baud (`115200`).
- No BQ response: verify `PC4/PC5` wiring, power, and wake sequence behavior.
- No CAN frames: verify scheduling enabled after startup, CAN bus wiring, transceiver presence, and bench termination.

See also:

- `pinout_and_signals.md`
- `logging_and_leds.md`
- `troubleshooting.md`
- `reference/chip_inventory.md`

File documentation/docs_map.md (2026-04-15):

# Docs Map

This file maps documents by user goal.

## First-time user flow

1. `getting_started.md`
2. `hardware_setup.md`
3. `pinout_and_signals.md`
4. `startup_and_flashing.md`
5. `bringup_checklist.md`

## Firmware developer flow

1. `system_overview.md`
2. `firmware_overview.md`
3. `code_map.md`
4. `communication.md`
5. `reference/firmware_reference.md`

## Debugger / maintainer flow

1. `logging_and_leds.md`
2. `troubleshooting.md`
3. `known_issues_and_resolutions.md`
4. `startup_and_flashing.md`
5. `reference/toolchain_and_programmer_reference.md`
6. `reference/chip_inventory.md`

## Hardware/component lookup flow

1. `pinout_and_signals.md`
2. `reference/hardware_reference.md`
3. `reference/chip_inventory.md`

## How the layers fit

- Onboarding layer: get a board running fast
- Architecture layer: understand code and data flow
- Operations layer: diagnose and recover failures
- Reference layer: quick facts (pins, chips, tools)

See diagram: `diagrams/documentation_relationship_map.md`

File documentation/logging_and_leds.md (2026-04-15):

# Logging and LEDs

## UART logging

- Log channel: USART2 via STLINK VCP (`PA2` TX / `PA3` RX)
- Default monitor speed: `115200` (`platformio.ini`)
- Log macros: `LOG_INFO`, `LOG_WARN`, `LOG_ERROR`, `LOG_DEBUG`

Open monitor:

```bash
pio device monitor -b 115200
```

## Typical startup/runtime logs

Examples from code paths:

- `BQ startup state: READY` or `FAILED`
- `FDCAN nominal timing: ...`
- `Thermistor fault mask=...`
- `BQ Keep-Alive Write FAILED repeatedly...`
- `PACK TOO HOT: ...`

## LED meanings (current code behavior)

| LED logical role | LED ID | Behavior |
|---|---|---|
| Therm subsystem indicator | `THERM_LED` (`LD1`) | Lit when `therm_status == FAILED` |
| CAN subsystem indicator | `CAN_LED` (`LD2`) | Lit when CAN status failed or scheduling disabled |
| Voltage/BQ subsystem indicator | `VOLT_LED` (`LD3`) | Lit when BQ state is not READY |

Additional behavior:

- Startup pulse: all LEDs pulse for 1 second in `main()`.
- Fatal error path (`Error_Handler`): all LEDs toggle indefinitely.

## Normal startup indicators

- One-time LED all-pulse at boot
- UART logs active shortly after init
- CAN periodic frames present once scheduling is enabled

## Abnormal indicators

- No UART output at all
- One subsystem LED stays lit continuously
- Repeating BQ keep-alive/fault poll failures
- CAN IDs missing despite successful build/flash

## No log output quick checks

1. Confirm terminal baud is `115200`.
2. Confirm STLINK VCP device enumerated on host.
3. Confirm target board is externally powered.
4. Confirm firmware reached `UART_Stlink_Init()` (not trapped early in error path).
5. Confirm PA2/PA3 mapping and board routing against schematic.

See also:

- `hardware_setup.md`
- `troubleshooting.md`

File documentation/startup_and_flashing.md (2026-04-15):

# Startup and Flashing

This is the primary bring-up and recovery guide for this repository.

## Preconditions

- Target board externally powered
- STLINK-V3MINIE connected over SWD (including NRST)
- Firmware built (`pio run -e nucleo_g474re`)

## Standard flash flow

1. Connect STLINK and target power.
2. Start STM32CubeProgrammer and confirm SWD connection.
3. Verify project bring-up settings (option bytes + NRST level; details below).
4. Flash firmware (CubeProgrammer or PlatformIO).
5. Reset/power-cycle and validate UART + CAN behavior.

## Fresh Chip / Brand-New Board Bring-Up

This step is mandatory for first-time chips/boards in this project.

1. Open STM32CubeProgrammer and connect with SWD.
2. Read and review option bytes related to boot source:
   - `nSWBOOT0`
   - `nBOOT0`
   - any BOOT0-related project boot fields shown by tool version
3. Apply the project's known-good boot profile so the MCU consistently boots user firmware from Flash on reset/power-cycle.
4. Set reset mode to **NRST Level 3** for this project during setup/flashing.
5. Program option bytes, then perform a full reset/power cycle.

> Important (project-specific): This repository has observed bring-up failures when boot option-byte configuration is wrong and when NRST mode is not set to the project's known-good value.

> Important (scope): NRST Level 3 is documented here as a project requirement, not a universal STM32 rule.

## Boot option-byte configuration issue (SWBOOT / nSWBOOT0 / nBOOT0)

Observed project behavior:

- Board may not boot application reliably after power cycle
- Board may look stuck in bootloader-like behavior
- Programming appears to work, but runtime behavior is inconsistent
- Board may appear to recover only after reprogramming

What to do:

- Use CubeProgrammer option-byte view and confirm boot-source configuration matches the team's known-good settings.
- Re-apply and cycle power after option-byte changes.
- Verify by cold boot, not only debugger reset.

Evidence notes in repo:

- STM32 Nucleo G4 board docs in `Docs/dm00556337-*.pdf` mention `nSWBOOT0`/`nBOOT0` BOOT0 behavior.
- Project code itself does not hard-code option-byte values; bring-up setup must be done with programmer tools.

## Project-specific NRST Level 3 requirement

For this project, use NRST Level 3 during flashing/setup because this was required to achieve reliable bring-up behavior.

- Use this in CubeProgrammer/programmer reset settings during fresh-chip setup and recovery attempts.
- If the exact electrical cause is needed, verify against schematic and lab measurements.

## Flashing with PlatformIO

```bash
pio run -e nucleo_g474re
pio run -e nucleo_g474re -t upload
```

## Flashing with CubeProgrammer

1. Connect via STLINK/SWD.
2. Load generated `.elf` or `.bin`.
3. Program and verify.
4. Reset/power cycle.

## Verify flashing success

- UART monitor shows normal startup logs (`115200` on STLINK VCP)
- Boot LED pulse occurs once
- CAN traffic includes IDs:
  - `0x18EEFF80`
  - `0x1839F380`
  - `0x1838F380`

## If the board only works after reprogramming

Likely causes in this project:

- Boot option-byte configuration mismatch (`nSWBOOT0`/`nBOOT0` path)
- Reset/debug configuration mismatch (NRST not set to project-known-good Level 3)
- Power-cycle path differs from debugger reset path

Recovery sequence:

1. Reconnect in CubeProgrammer.
2. Re-check and re-apply boot option-byte profile.
3. Set NRST to Level 3 (project requirement).
4. Reflash firmware.
5. Do a full power cycle and retest without debugger-assisted reset.

## If flashing fails

- Check SWD wiring and target power first.
- Lower SWD speed and retry.
- Use mass erase if device is in a bad state.
- Re-apply fresh-chip bring-up sequence above.

See also:

- `hardware_setup.md`
- `troubleshooting.md`
- `known_issues_and_resolutions.md`
- `bringup_checklist.md`

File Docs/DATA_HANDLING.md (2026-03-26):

# Data Handling Mechanism

## Overview

The EV Active Sensor Adapter does not maintain long-term persistent storage on-board. All measurements are held transiently in RAM as a structured data model designed to support deterministic sampling, validation, and CAN-FD transmission. This design choice reduces complexity and failure modes (no file system, no flash wear, no SD reliability concerns) while ensuring timing predictability. Long-term storage and retrieval are handled by the vehicle logging manager, which timestamps and records CAN-FD frames for post-run analysis.

Raw thermistor voltages are sampled by the STM32 ADC and converted into temperature values using a lookup table with linear interpolation. After conversion, values are range-checked and assigned validity flags. Each update also records a timestamp and sequence counter to support freshness evaluation and diagnostic reasoning.

The firmware packs the current validated values into periodic CAN-FD frames based on the configured transmission schedule (including round-robin behavior for individual thermistor reporting). Fault conditions (ADC timeout, sensor open/short, invalid sample) are represented as a bitfield and exposed through diagnostic CAN fields and user-visible indicators (LED and UART messages). This architecture provides a clear separation between measurement acquisition, in-memory representation, message packing, and off-board storage, enabling reliable telemetry during vehicle operation and straightforward retrieval from the logging manager.

---

## Data Lifecycle Diagram

```mermaid
flowchart LR
    subgraph ACQUIRE ["1. Acquisition"]
        RAW["Raw ADC Samples<br/>0-4095 counts<br/>10 channels"]
    end

    subgraph CONVERT ["2. Conversion"]
        ENG["Engineering Units<br/>int8_t degrees C<br/>lookup table + interpolation"]
    end

    subgraph VALIDATE ["3. Validation"]
        VALID["Validated Data<br/>range checked<br/>open/short detect<br/>freshness timestamp"]
    end

    subgraph BUFFER ["4. Buffering"]
        BUF["In-Memory Buffers<br/>s_temps[10]<br/>g_can_ctx fields<br/>fault_flags"]
    end

    subgraph PACK ["5. Frame Packing"]
        FRAME["CAN Payloads<br/>8-byte frames<br/>checksum appended<br/>temps as uint8_t (signed on-wire)"]
    end

    subgraph QUEUE ["6. TX Queue"]
        TXFIFO["FDCAN TX FIFO<br/>HAL enqueue<br/>rate-controlled"]
    end

    subgraph STORE ["7. External Storage"]
        LOGGER["Logging Manager<br/>timestamped frames<br/>post-run retrieval"]
    end

    RAW --> ENG --> VALID --> BUF --> FRAME --> TXFIFO --> LOGGER
```

---

## Data Dictionary (Firmware Resident Data)

### Thermistor Measurement Data

| Data Item | Type / Size | Units | Source | Update Rate | Validity Rules | Where Used |
|---|---|---|---|---|---|---|
| `thermistor_adc_values[10]` | `uint16_t[10]` | ADC counts (0-4095) | STM32 ADC1 | 100 ms (configurable) | Range 0-4095; 0 or 4095 indicates open/short | Conversion input |
| `s_temps[10]` | `int8_t[10]` | Degrees Celsius | Lookup table conversion | On ADC update | -40 to +125 C clamp; invalid if ADC out of range | CAN packing, min/max/avg calc |
| `s_num_temps` | `uint8_t` | Count | Configuration | Static | Must be 1-10 | Iteration bounds |

### CAN Application Context (`g_can_ctx`)

| Data Item | Type / Size | Units | Source | Update Rate | Validity Rules | Where Used |
|---|---|---|---|---|---|---|
| `thermistors.thermistor_adc_values[10]` | `uint16_t[10]` | ADC counts | ADC_ServiceTask | 100 ms | Same as above | CAN encoding |
| `thermistors.num_active` | `uint8_t` | Count | ADC_ServiceTask | On update | 0-10 | Message assembly |
| `voltages.voltage_adc_values[14]` | `uint16_t[14]` | ADC counts | SPI (MAX17841) | 200 ms | Valid if SPI OK | Future use |
| `voltages.num_active` | `uint8_t` | Count | SPI driver | On update | 0-14 | Future use |
| `therm_index` | `uint8_t` | Index | Round-robin logic | Per General Broadcast | Wraps 0 to num_active-1 | General Broadcast encoding |
| `last_claim_ms` | `uint32_t` | Milliseconds | HAL_GetTick | On J1939 Claim send | Monotonic | 200 ms period check |
| `last_bms_ms` | `uint32_t` | Milliseconds | HAL_GetTick | On BMS Broadcast send | Monotonic | 100 ms period check |
| `last_general_ms` | `uint32_t` | Milliseconds | HAL_GetTick | On General Broadcast send | Monotonic | 100 ms period check |

### Timing and Freshness

| Data Item | Type / Size | Units | Source | Update Rate | Validity Rules | Where Used |
|---|---|---|---|---|---|---|
| `HAL_GetTick()` | `uint32_t` | Milliseconds | SysTick (1 ms) | Continuous | Monotonic, wraps at ~49 days | All timing decisions |
| `s_last_rx_ms` | `uint32_t` | Milliseconds | CAN RX handler | On each RX frame | Updated per frame received | TX gating (RX_GRACE_MS check) |

### Fault and Status Flags

| Data Item | Type / Size | Units | Source | Update Rate | Validity Rules | Where Used |
|---|---|---|---|---|---|---|
| `g_fdcan1.ErrorCode` | `uint32_t` | Bitfield | HAL FDCAN driver | On error event | Latched until cleared or queried | Error logging, diagnostics |
| Sensor open/short | Derived | Boolean per channel | ADC value = 0 or 4095 | Per sample | Implicit from ADC bounds | Fault byte in CAN payload |
| CAN TX fail count | (implicit) | Counter | CAN_Comm_SendExt return | Per TX attempt | Logged on failure | Debug output |

### Lookup Table Structure

| Data Item | Type / Size | Units | Source | Update Rate | Validity Rules | Where Used |
|---|---|---|---|---|---|---|
| `ThermistorTableEntry_t` | `struct { uint16_t adc; int8_t temp; }` | ADC counts, Degrees C | Compile-time constant | Static | ADC values descending; 115 entries | Binary search + interpolation |

---

## CAN Message Schedule

| Message | CAN ID (Extended) | Period | Payload Size | Payload Contents |
|---|---|---|---|---|
| J1939 Address Claim | `0x18EEFF80` | 200 ms | 8 bytes | Fixed identity fields (unique_id, bms_target, module, constants) |
| BMS Broadcast | `0x1839F380` | 100 ms | 8 bytes | Module number, avg temp, max temp, avg ID, relative ID, fault byte, max ID, checksum |
| General Broadcast | `0x183BF380` | 100 ms (round-robin) | 8 bytes | Module number, thermistor ID, temperature, reserved bytes, checksum |

---

## Data Conversion Pipeline

### ADC to Temperature Conversion

1. **Raw Sample**: STM32 ADC reads thermistor voltage divider (12-bit, 0-4095 counts)
2. **Lookup**: Binary search finds two nearest entries in 115-entry table (ADC descending order)
3. **Interpolation**: Linear interpolation between bracketing entries
4. **Clamp**: Result clamped to int8_t range (-128 to +127, practical range -40 to +125)
5. **Storage**: Stored in `s_temps[]` as signed 8-bit integer

### Temperature to CAN Payload

1. **Read**: `s_temps[i]` is int8_t (-40 to +125 typical)
2. **Cast**: `(uint8_t)s_temps[i]` preserves two's complement bit pattern
3. **Pack**: Placed into `payload[n]` as unsigned byte
4. **Wire**: BMS interprets byte as signed int8_t (e.g., 0xE2 = -30)

---

## Persistence and Retrieval Strategy

### On-Board Storage

- **Type**: RAM only (no Flash, no SD card, no EEPROM)
- **Scope**: Current measurement cycle buffers, timestamps, fault flags
- **Lifetime**: Valid while powered; cleared on reset

### Off-Board Storage

- **Device**: Vehicle logging manager (separate ECU)
- **Format**: Raw CAN-FD frames with timestamps
- **Retrieval**: Post-run download via logging manager interface

### Design Rationale

| Concern | On-Board Storage | Off-Board (Logger) |
|---|---|---|
| Complexity | None (no filesystem) | Logger handles storage |
| Reliability | No wear, no corruption risk | Logger manages media |
| Determinism | Guaranteed timing | Decoupled from adapter |
| Power | Minimal (RAM only) | Logger has own power |
| Retrieval | N/A | Team downloads logs |

This architecture keeps the sensor adapter simple, deterministic, and low-power. The logging manager provides timestamped CAN frame capture for post-run analysis, debugging, and compliance verification.

---

## Data Integrity Mechanisms

### Transmission Integrity

| Mechanism | Implementation | Purpose |
|---|---|---|
| Checksum | Sum of payload bytes + 0x39 + length, low 8 bits | Detect payload corruption |
| CAN CRC | Hardware (FDCAN peripheral) | Bit-level error detection |
| Sequence | Round-robin index in General Broadcast | Detect missed frames |
| Freshness | Timestamps in g_can_ctx | Age-gate stale data |

### Fault Detection

| Fault | Detection Method | Response |
|---|---|---|
| Sensor open | ADC = 4095 (rail high) | Fault bit set in payload |
| Sensor short | ADC = 0 (rail low) | Fault bit set in payload |
| ADC timeout | Service task watchdog | Log error, use last valid |
| CAN TX fail | HAL return code check | Log error, retry next cycle |
| CAN bus-off | HAL state check | Log error, attempt recovery |

---

## Summary

The data handling mechanism provides:

1. **Clear data lifecycle**: Raw samples through validated engineering units to CAN frames
2. **Deterministic timing**: Fixed sample and transmit periods with timestamp tracking
3. **Robust validation**: Range checks, open/short detection, freshness gating
4. **Minimal on-board storage**: RAM-only design eliminates filesystem complexity
5. **Off-board persistence**: Logging manager captures all CAN traffic with timestamps
6. **Data integrity**: Checksums, hardware CRC, sequence counters, fault flags

This design satisfies the requirement to "show the code" for data handling by documenting where data lives (RAM buffers), what format it uses (defined structs and types), how long it is valid (timestamps and freshness checks), how it moves (ADC to conversion to CAN), and how integrity is maintained (checksums, CRC, fault detection).

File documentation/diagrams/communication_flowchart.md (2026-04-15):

# Communication Flowchart

```mermaid
flowchart LR
    A[Thermistor ADC samples] --> B[Temperature conversion + fault mask]
    B --> C[CAN cache update]

    D[BQ keep-alive + fault polls + cell reads] --> E[External voltage cache update]
    E --> C

    F[TIM7 schedule flags] --> G[CAN_SendMessages]
    C --> G

    G --> H1[0x18EEFF80 claim]
    G --> H2[0x1839F380 BMS summary]
    G --> H3[0x1838F380 general thermistor]
    G --> H4[0x18FF3000..003 external volt segments]

    H1 --> I[FDCAN1 TX]
    H2 --> I
    H3 --> I
    H4 --> I

    I --> J[CAN bus logger / BMS]

    K[Runtime events/faults] --> L[LOG_INFO/WARN/ERROR/DEBUG]
    L --> M[USART2 STLINK VCP 115200]
```

## Notes

- CAN transmission scheduling is interrupt-flag driven but sent in task context.
- BQ comm loss transitions voltage path to failed state while thermistor CAN path continues.

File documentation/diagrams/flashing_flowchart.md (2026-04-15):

# Flashing Flowchart

```mermaid
flowchart TD
    A[Connect STLINK SWD and external target power] --> B[Open STM32CubeProgrammer]
    B --> C[Connect to target]
    C --> D{Fresh chip or first bring-up?}

    D -->|Yes| E[Review option bytes]
    E --> F[Check boot fields nSWBOOT0 and nBOOT0]
    F --> G[Apply project-known-good boot option-byte profile]
    G --> H[Set reset mode: NRST Level 3 project requirement]
    H --> I[Program option bytes and reset/power cycle]

    D -->|No| J[Keep verified settings]
    I --> K[Flash firmware image]
    J --> K

    K --> L[Verify programming success]
    L --> M[Power cycle and run]
    M --> N{Board stable after cold boot?}

    N -->|Yes| O[Open UART logs and CAN monitor; validate runtime]
    N -->|No| P[Run recovery: re-check boot option bytes + NRST Level 3 and reflash]
    P --> M
```

## Required project checks

- CubeProgrammer option-byte review is mandatory on fresh chips.
- `nSWBOOT0` / `nBOOT0` boot behavior must be verified for this project.
- Use NRST Level 3 during flashing/setup for reliable bring-up in this project.

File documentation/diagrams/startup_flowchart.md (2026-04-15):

# Startup Flowchart

```mermaid
flowchart TD
    A[Power On / Reset] --> B[HAL_Init]
    B --> C[SystemClock_Config]
    C --> D[LED_Init and clocks_configure_all]
    D --> E[UART_Stlink_Init USART2]
    E --> F[UART_BQ79616_Init USART1]
    F --> G[Therm_App_Init]
    G --> H[CAN_App_Init 1 Mbps]
    H --> I[Timers_Init]
    I --> J[CAN scheduling disabled initially]
    J --> K[Volt_RunBlockingStartup]

    K -->|BQ_STATE_READY| L[Enable CAN scheduling normal]
    K -->|BQ_STATE_FAILED| M[Enable CAN scheduling with fault-reporting mode]

    L --> N[Enter main loop]
    M --> N

    N --> O[Therm_ServiceTask]
    O --> P[CAN_ServiceTask]
    P --> Q[Volt_ServiceTask]
    Q --> O
```

## Observed behavior anchors

- Startup includes one-time `LED_All_Pulse(1000u)` in `main()`.
- BQ startup is a gate before periodic CAN scheduling is released.

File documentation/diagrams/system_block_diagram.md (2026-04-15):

# System Block Diagram

```mermaid
flowchart LR
    subgraph HW[Hardware]
        T1[Thermistor Inputs x10]
        BQ[BQ79616 Chain]
        CANBUS[CAN Bus / Logger / BMS]
        STLINK[STLINK-V3MINIE]
        PWR[External Target Power]
    end

    subgraph MCU[STM32G474 Firmware]
        ADC[ADC1 Thermistor Sampling]
        THERM[Therm Conversion and Fault Cache]
        VMON[Volt Service / BQ Driver]
        CANENC[CAN Message Encoding]
        FDCAN[FDCAN1 TX]
        UARTLOG[USART2 Log Output]
    end

    T1 --> ADC --> THERM --> CANENC --> FDCAN --> CANBUS
    BQ <-- USART1 PC4/PC5 --> VMON --> CANENC
    STLINK -. SWD + VCP .-> MCU
    MCU --> UARTLOG --> STLINK
    PWR --> MCU

    note1[STLINK-V3MINIE provides debug and VCP but does not power target]
```

## Notes

- Therm and BQ paths are both reflected in CAN output.
- BQ failure still allows thermistor CAN path to continue in degraded mode.

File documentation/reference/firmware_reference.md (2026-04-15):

# Firmware Reference

Compact firmware facts and file locations.

## Build/profile

- Build system: PlatformIO (`platformio.ini`)
- Target env: `nucleo_g474re`
- Upload protocol: `stlink`

## Core runtime flow

- Entry: `src/main.c`
- Startup orchestration: `src/init.c` (`System_AppInit`)
- Main task loop order:
  1. `Therm_ServiceTask`
  2. `CAN_ServiceTask`
  3. `Volt_ServiceTask`

## Key modules

- Thermistor acquisition: `src/therm.c`, `include/therm.h`
- Therm conversion table: `src/thermistor_table.c`, `include/thermistor_table.h`
- CAN transport: `src/can.c`, `include/can.h`
- CAN message packing/scheduling: `src/can_messages.c`, `include/can_messages.h`
- BQ interface: `src/bq79616.c`, `include/bq79616.h`
- BQ service wrapper/state: `src/volt.c`, `include/volt.h`
- Timers and flags: `src/timer.c`, `include/timer.h`
- Logging/UART: `src/uart.c`, `include/uart.h`
- LED control: `src/led.c`, `include/led.h`
- Error path: `src/error_handling.c`, `include/error_handling.h`

## Important runtime constants/IDs

- BQ UART baud: `1000000` (`BQ_BAUDRATE`)
- Log UART baud: `115200`
- Default CAN bitrate: `1000 kbps` (`CAN_APP_DEFAULT_KBPS`)
- Main CAN IDs:
  - `0x18EEFF80` claim
  - `0x1839F380` BMS summary
  - `0x1838F380` general thermistor
  - `0x18FF3000..003` external voltage segments

## Known architectural behavior

- BQ startup is blocking during init.
- If BQ fails, thermistor + CAN path remains active with fault-reporting behavior.
- CAN scheduling uses TIM7 flags and non-ISR send operations.

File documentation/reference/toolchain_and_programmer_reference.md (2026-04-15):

# Toolchain and Programmer Reference

## Build and flash tools

| Tool | Use |
|---|---|
| PlatformIO (`pio`) | Build and upload firmware |
| STM32CubeProgrammer | Option-byte configuration, direct flash, recovery |
| STLINK-V3MINIE | Physical debug/program probe and VCP bridge |

## Typical commands

Build:

```bash
pio run -e nucleo_g474re
```

Upload:

```bash
pio run -e nucleo_g474re -t upload
```

Open serial monitor:

```bash
pio device monitor -b 115200
```

## Programmer setup notes (project)

- For fresh chips/new boards, do CubeProgrammer setup first.
- Review and configure boot option bytes (`nSWBOOT0` / `nBOOT0` path) per project bring-up profile.
- Set reset mode to NRST Level 3 for this project during setup/flashing.

## STLINK-V3MINIE notes from checked-in docs

- Provides SWD debug/program functionality.
- Provides VCP for UART logs.
- Does not provide target application power (use external power source).

## CAN and bench validation tools

- Captured logs in repo:
  - `Other/can_log.txt`
  - `Other/mycan_log.txt`
  - `Other/can_diag_campaign_20260412_234404.log`
- Data scripts:
  - `Other/convertingtoexcel.py`
  - `Other/comparing.py`

## Recovery-first sequence

1. Connect SWD + external power.
2. Use CubeProgrammer to verify connection and option bytes.
3. Apply project boot/reset settings.
4. Flash firmware.
5. Power-cycle and verify UART + CAN behavior.

## Related references

- `../pinout_and_signals.md`
- `hardware_reference.md`
- `chip_inventory.md`

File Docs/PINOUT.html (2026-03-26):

# Pin Assignments — STM32G474RET6 (Current)

Source of truth for the bring-up build with UART console on USART1 (PC4/PC5) and BQ79616 transport on USART2 (PA2/PA3).

## Digital I/O & Comms

Block | Signal / Use | Pin | AF / Mode | Notes
USART1 | TX (console/log) | PC4 | AF7 USART1 | External header; used for Log_Printf
USART1 | RX (console/log) | PC5 | AF7 USART1 | External header; ST-Link VCP only if patched
USART2 | TX (BQ79616) | PA2 | AF7 USART2 | Blocking TX to BQ79616
USART2 | RX (BQ79616) | PA3 | AF7 USART2 | Blocking RX from BQ79616
FDCAN1 | RX | PA11 | AF9 FDCAN1 | 1 Mbps default
FDCAN1 | TX | PA12 | AF9 FDCAN1 | 1 Mbps default
SPI1 | SCK | PA5 | AF5 SPI1 | MAX17841B / ASCI
SPI1 | MISO | PA6 | AF5 SPI1
SPI1 | MOSI | PA7 | AF5 SPI1
SPI1 | CS (software) | PA4 | GPIO output | ASCI / MAX17841B chip select
LED1 | Status | PA9 | GPIO output | Active high
LED2 | Status | PA8 | GPIO output | Active high
LED3 | Status | PC9 | GPIO output | Active high
LED4 | Status | PC8 | GPIO output | Active high
LED5 | Fault indicator | PC7 | GPIO output | Active high
Spare | GPIO | PC6 | GPIO | Unused
Spare | GPIO/Analog header | PB15 | GPIO/Analog | Unused
Spare | GPIO/Analog header | PB13 | GPIO/Analog | Unused

## Analog Inputs (ADC1)

Channel | Pin
IN1 | PA0
IN2 | PA1
IN5 | PB14
IN6 | PC0
IN7 | PC1
IN8 | PC2
IN9 | PC3
IN11 | PB12
IN14 | PB11
IN15 | PB0

## Notes

- USART mapping changed: USART1 (PC4/PC5) remains the logging/console channel; USART2 (PA2/PA3) is now dedicated to the BQ79616 driver.
- PA4 stays reserved as the software CS for the MAX17841B (ASCI). Hardware NSS on PA3 is no longer available because PA3 is USART2 RX.
- FDCAN1 is on the standard Nucleo pins PA11/PA12.
- All LEDs are active-high; LED5 is reserved as a fault/Error_Handler() indicator.
- No DMA is used for either UART; both run in blocking mode for bring-up.

Pin Assignments — STM32G474RET6 (Current)

Digital I/O & Comms

Analog Inputs (ADC1)

Notes

≡

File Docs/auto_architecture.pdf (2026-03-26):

auto_architecture.md | 2026-02-05

# EV Active Sensor Adapter - Firmware System Architecture

## System Overview

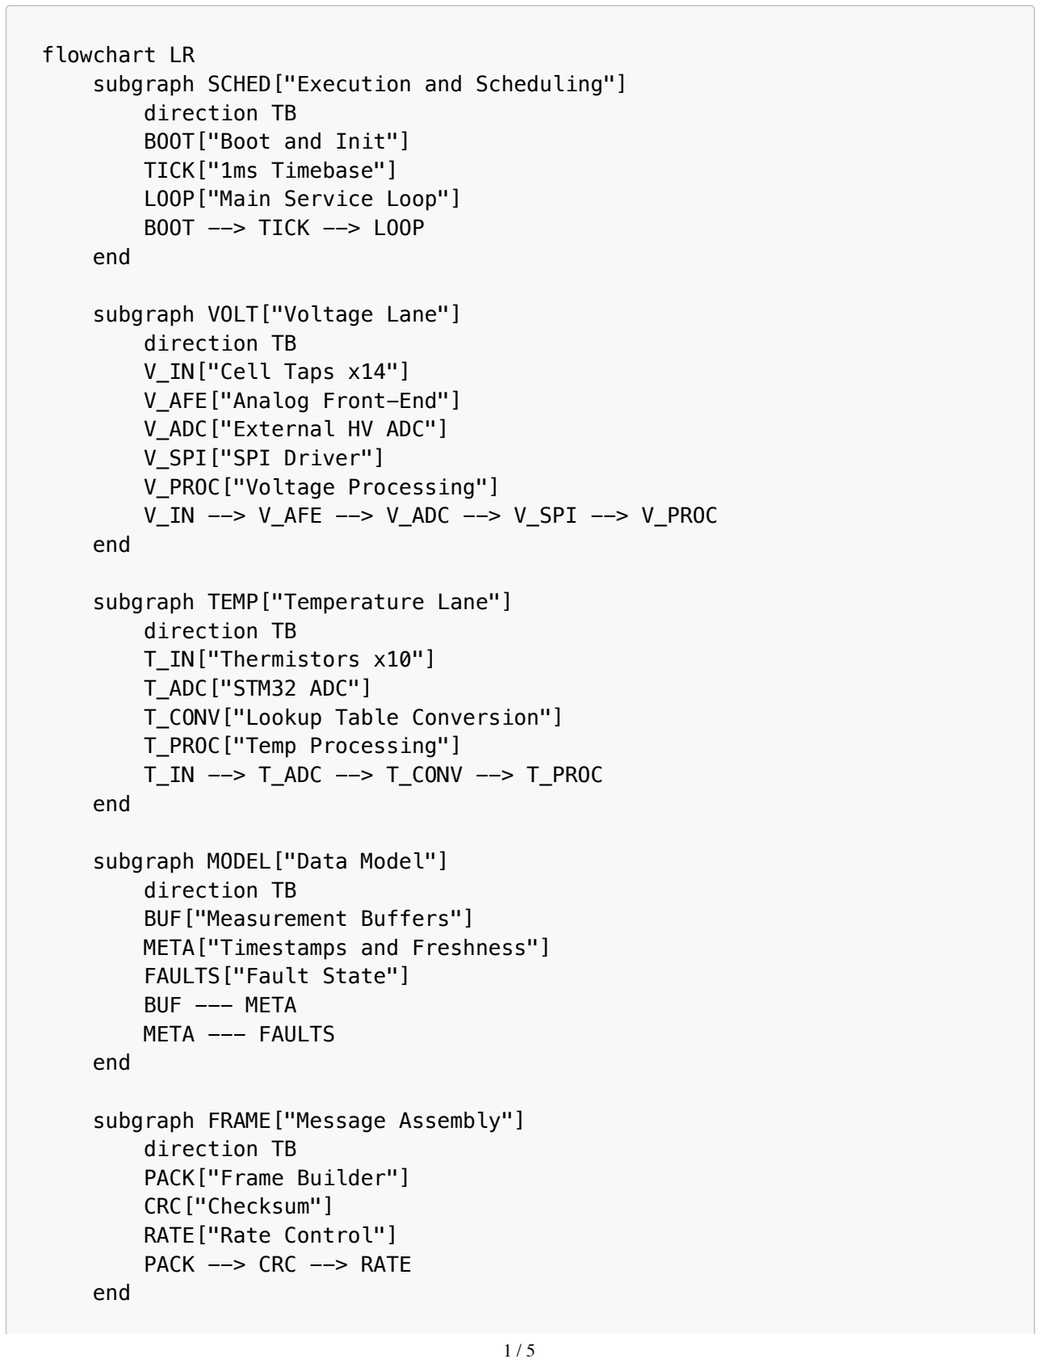
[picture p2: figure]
flowchart LR subgraph SCHED["Execution and Scheduling"] direction TB BOOT["Boot and Init"] TICK["1ms Timebase"] LOOP["Main Service Loop"] BOOT --> TICK --> LOOP; end; subgraph VOLT["Voltage Lane"] direction TB V_IN["Cell Taps x14"] V_AFE["Analog Front-End"] V_ADC["External HV ADC"] V_SPI["SPI Driver"] V_PROC["Voltage Processing"]; subgraph TEMP["Temperature Lane"] direction TB T_IN["Thermistors x10"] T_ADC["STM32 ADC"] T_CONV["Lookup Table Conversion"] T_PROC["Temp Processing"] T_IN --> T_ADC --> T_CONV --> T_PROC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

V_IN --> V_AFE --> V_ADC --> V_SPI --> V_PROC

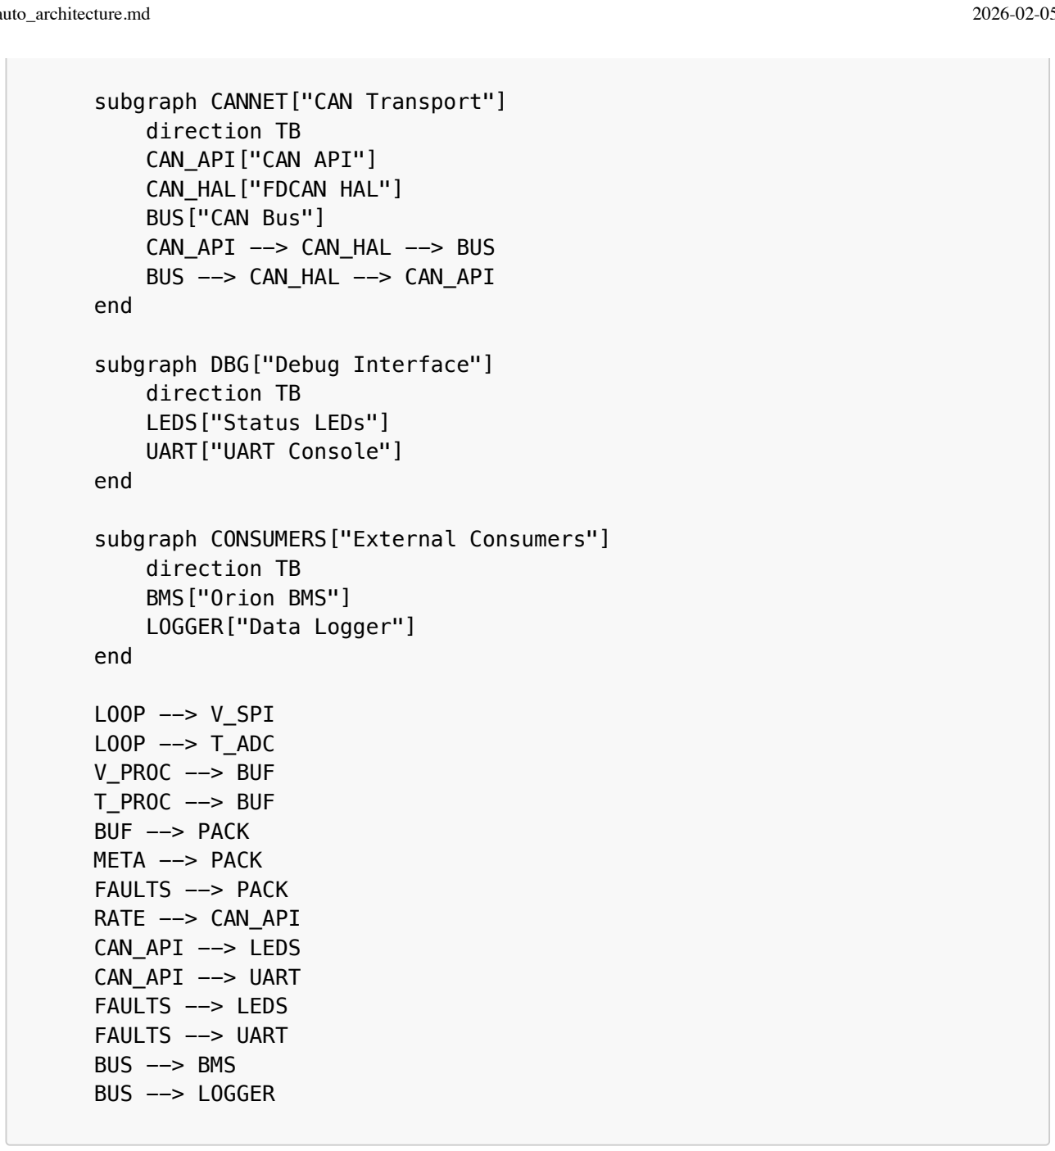
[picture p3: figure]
subgraph CANNET["CAN Transport"] direction TB CAN_API["CAN API"] CAN_HAL["FDCAN HAL"] BUS["CAN Bus"] CAN_API --> CAN_HAL --> BUS BUS --> CAN_HAL --> CAN_API; end; subgraph DBG["Debug Interface"] direction TB LEDS["Status LEDs"] UART["UART Console"]; subgraph CONSUMERS["External Consumers"] direction TB BMS["Orion BMS"] LOGGER["Data Logger"]; LOOP --> V_SPI LOOP --> T_ADC V_PROC --> BUF T_PROC --> BUF BUF --> PACK META --> PACK FAULTS --> PACK RATE --> CAN_API CAN_API --> LEDS CAN_API --> UART FAULTS --> LEDS FAULTS --> UART BUS --> BMS BUS --> LOGGER

## Timing Constraints

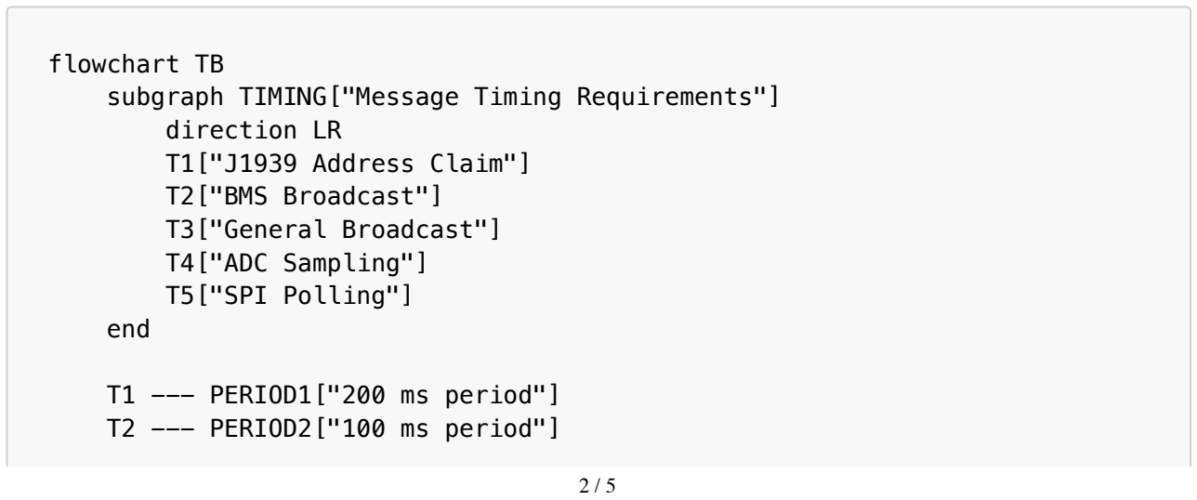
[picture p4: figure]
flowchart TB subgraph TIMING["Message Timing Requirements"] direction LR T1["J1939 Address Claim"] T2["BMS Broadcast"] T3["General Broadcast"] T4["ADC Sampling"] T5["SPI Polling"]; end; T1 --- PERIOD1["200 ms period"] T2 --- PERIOD2["100 ms period"]

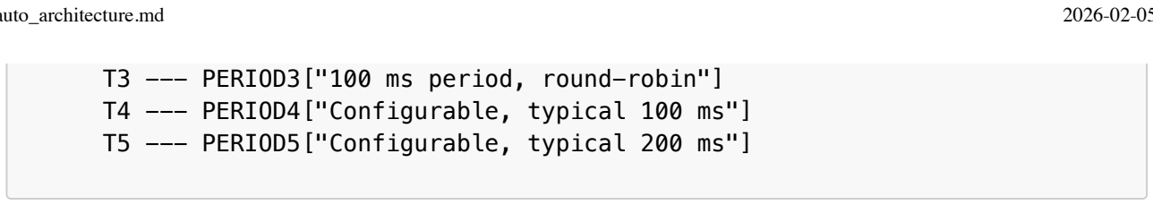
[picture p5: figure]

T3 --- PERIOD3["100 ms period, round-robin"] T4 --- PERIOD4["Configurable, typical 100 ms"] T5 --- PERIOD5["Configurable, typical 200 ms"]

## Data Flow Detail

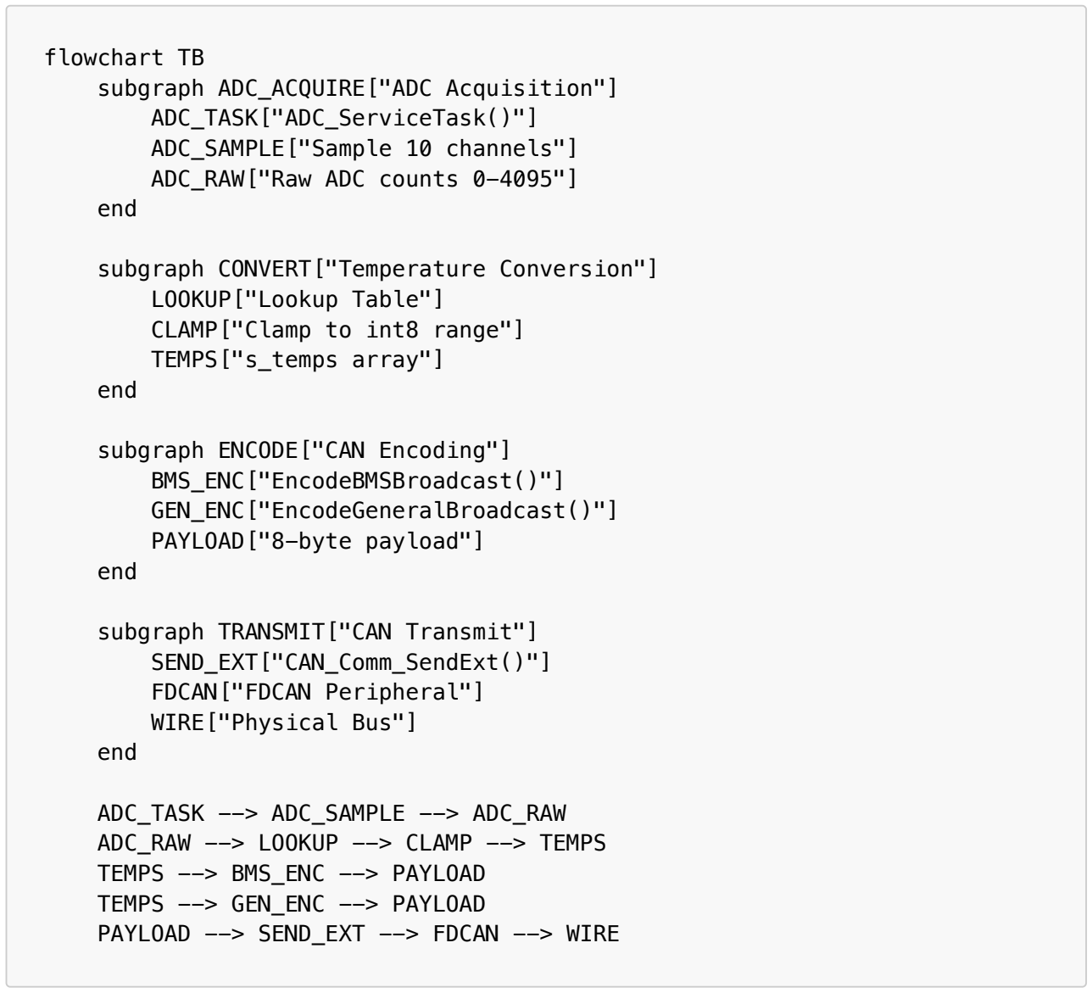
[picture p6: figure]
flowchart TB subgraph ADC_ACQUIRE["ADC Acquisition"] ADC_TASK["ADC_ServiceTask()"] ADC_SAMPLE["Sample 10 channels"] ADC_RAW["Raw ADC counts 0-4095"]; end; subgraph CONVERT["Temperature Conversion"] LOOKUP["Lookup Table"] CLAMP["Clamp to int8 range"] TEMPS["s_temps array"]; subgraph ENCODE["CAN Encoding"] BMS_ENC["EncodeBMSBroadcast()"] GEN_ENC["EncodeGeneralBroadcast()"] PAYLOAD["8-byte payload"]; subgraph TRANSMIT["CAN Transmit"] SEND_EXT["CAN_Comm_SendExt()"] FDCAN["FDCAN Peripheral"] WIRE["Physical Bus"]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

## Module Responsibilities

Module | File | Purpose | Timing
Main | main.c | Init and main loop | Continuous
ADC | adc.c | Sample thermistor channels | Periodic
SPI | spi.c | Poll MAX17841 for cell data | Periodic
Thermistor | thermistor_table.c | ADC to temperature lookup | On demand
CAN Messages | can_messages.c | Encode BMS and General frames | On demand

Module | File | Purpose | Timing
CAN Core | can.c | FDCAN init, send, receive | Periodic
Timer | timer.c | HAL_GetTick based timing | 1 ms tick
Log | log.c | UART debug output | On demand
LED | led.c | Status indication | Periodic
Error | error_handling.c | Fault handling | On event

## CAN Message Schedule

Message | CAN ID | Period | Payload
J1939 Address Claim | 0x18EEFF80 | 200 ms | 8 bytes fixed
BMS Broadcast | 0x1839F380 | 100 ms | Module summary
General Broadcast | 0x183BF380 | 100 ms | Single thermistor, round-robin

## Temperature Data Path

flowchart LR
THERM["Thermistor"] --> DIVIDER["Voltage Divider"] --> PIN["ADC Pin"] PIN --> SAMPLE["ADC Sample"] --> COUNT["0-4095 count"]
COUNT --> TABLE["Lookup Table"] --> SIGNED["int8_t temp"]
SIGNED --> CAST["cast to uint8_t"] --> WIRE["CAN payload byte"] WIRE --> BMS["Orion BMS interprets as int8_t"]

## Initialization Sequence

flowchart TB
START["Power On"] --> HAL["HAL_Init()"] HAL --> CLK["SystemClock_Config()"] CLK --> GPIO["GPIO_App_Init()"]
GPIO --> UART["UART_Log_Init()"]
UART --> ADC["ADC_App_Init()"]
ADC --> SPI["SPI_App_Init()"] SPI --> CAN["CAN_App_Init()"] CAN --> LED["LED_Init()"]
LED --> LOOP["Enter Main Loop"]

## Main Loop Execution

LOOP["Main Loop Start"] --> CHECK_ADC{"ADC period elapsed?"}

CHECK_ADC -- yes --> RUN_ADC["ADC_ServiceTask()"] CHECK_ADC -- no --> CHECK_SPI
RUN_ADC --> CHECK_SPI{"SPI period elapsed?"} CHECK_SPI -- yes --> RUN_SPI["SPI_ServiceTask()"] CHECK_SPI -- no --> CHECK_CAN
RUN_SPI --> CHECK_CAN{"CAN period elapsed?"} CHECK_CAN -- yes --> RUN_CAN["CAN_ServiceTask()"] CHECK_CAN -- no --> LOOP
RUN_CAN --> LOOP

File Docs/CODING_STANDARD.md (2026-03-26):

# Coding Standard Alignment

This project follows the [CMU C Coding Standard](https://users.ece.cmu.edu/~eno/coding/CCodingStandard.html).  
The key interpretations that now guide this codebase are summarised below so contributors
have a concise checklist alongside the upstream reference.

1. **File structure and headers**  
   - Every `.c` file begins with a short block comment describing its role.  
   - Includes are grouped: project headers first, then standard headers.  
   - File-scope `static` helpers and data are listed before public functions.

2. **Naming and scope**  
   - Constants use `SCREAMING_SNAKE_CASE`.  
   - Internal helpers are declared `static` to avoid leaking symbols.  
   - Each module encapsulates its own timing/context state (for example,
     `src/adc.c:24` tracks the next ADC run without leaking globals).

3. **Documentation and comments**  
   - Functions carry one-line summaries that describe purpose, side effects,
     and noteworthy implementation details (see `src/spi.c:32`).  
   - Complex sequences (e.g., MAX17841B command transactions) include inline
     comments explaining timing and error handling.

4. **Defensive programming**  
   - All public functions validate pointers and lengths up-front and return
     early when arguments are invalid.  
   - Configuration routines (clock, peripheral init) log failures before
     invoking `Error_Handler()` so issues remain traceable (`src/main.c:25-44`).

5. **Cooperative scheduling**  
   - The `while(true)` loop in `src/main.c` dispatches `ADC_ServiceTask`,
     and `SPI_ServiceTask`, letting each module track its
     own timing state (no central scheduler struct).  
   - Task bodies are short and self-contained, satisfying the guideline that
     loop bodies should call functions rather than contain complex logic.

When adding new modules, follow the same pattern:

```
/*
 * ===========================================================================
 * File: foo.c
 * Description: ...
 * ===========================================================================
 */
```

Group related declarations, explicitly document error paths, and avoid
magic numbers by introducing `#define` constants near the top of the file.
For quick reference, keep this document open alongside the CMU standard.

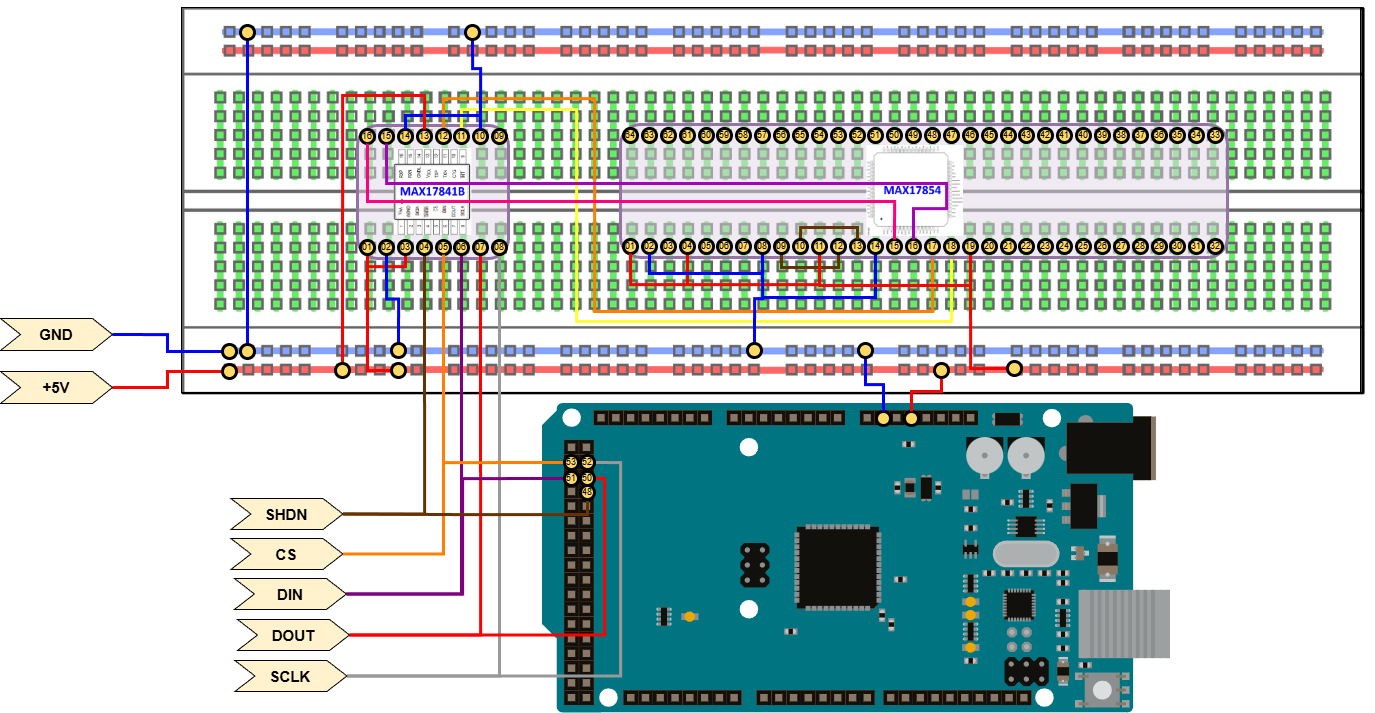
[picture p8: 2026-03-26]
Docs/SPI_ADC_BREADBOARD.drawio.png

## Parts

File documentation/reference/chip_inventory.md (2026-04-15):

# Chip Inventory and Board Components

This file captures the chips and major hardware components referenced in this repository and their status in the current firmware.

## A) Active in current firmware path

| Component | Role in project | Evidence in repo |
|---|---|---|
| STM32G474 (STM32G474xx family) | Main MCU running firmware | `platformio.ini`, `src/*.c`, `include/*.h` |
| BQ79616 | Battery monitor UART chain interface | `src/bq79616.c`, `include/bq79616.h`, `REGISTER_REFERENCE.md`, `QUICK_START_GUIDE.md` |
| STLINK-V3MINIE | SWD programming/debug + UART VCP bridge | `Docs/um2910-*.pdf`, `Docs/stlink-v3minie.pdf` |

## B) Present in checked-in hardware docs (verify board population)

| Component / document | Typical purpose | Status note |
|---|---|---|
| ISO1050 (`Docs/iso1050.pdf`) | CAN transceiver/isolation reference | Not directly referenced in active source; verify against actual board BOM/schematic |
| MAX17841B / MAX17854 docs (`Docs/MAX17841B.pdf`, `Docs/MAX17854.pdf`, EV kit docs) | Battery-monitor family references | Not active in current STM32 source path; treat as reference material |
| Nucleo G474 board docs/schematic (`Docs/dm00556337-*.pdf`, `Docs/mb1367-g474re-c05_schematic.pdf`) | Board-level pin/boot/debug behavior reference | Useful for bring-up, especially BOOT0/option-byte context |

## C) Legacy/reference content in repo

| Component family | Where found | Status note |
|---|---|---|
| TMS570 sample environment | `TI_Ref_Code/bq79616_sample_code/*` | Legacy reference/sample code; not current target firmware |
| MSP430 docs (`Docs/msp430fr2355.pdf`, `Docs/slau680.pdf`) | Reference docs | Not part of active STM32 firmware path |

## Project setup implications

- Build/flash/debug workflow is STM32G474 + STLINK-V3MINIE based.
- BQ79616 bring-up behavior (wake, keep-alive, fault handling) is implemented and required for full voltage path operation.
- CAN transceiver hardware details should be verified against your board-level schematic/BOM before making electrical assumptions.

## Required bring-up checks tied to these components

1. STM32 option-byte and boot setup in CubeProgrammer (`nSWBOOT0` / `nBOOT0` path).
2. Project reset requirement: NRST Level 3.
3. External target power present (STLINK does not power the target application).
4. BQ UART wiring and wake path validated.

See also:

- `../startup_and_flashing.md`
- `../pinout_and_signals.md`
- `hardware_reference.md`

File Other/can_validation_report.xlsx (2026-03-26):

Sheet: Summary
CAN ID Presence Comparison
CAN ID | Expected Description | Module Count | MyCAN Count | Status
18EEFF80 | J1939 Address Claim Broadcast | 106 | 1726 | MATCHING PRESENCE
1839F380 | Thermistor Module -> BMS Broadcast | 212 | 2182 | MATCHING PRESENCE
1838F380 | Thermistor General Broadcast | 272 | 2182 | MATCHING PRESENCE
80 | Legacy Broadcast Message - RESERVED | 0 | 0 | MISSING FROM BOTH
Expected Field Coverage vs Each File
CAN ID | Expected Fields | Missing in Module | Missing in MyCAN | Module Field Coverage OK | MyCAN Field Coverage OK
18EEFF80 | 0x1e (constant), 0x40 (constant), 0x90 (constant), bms target address, thermistor module number, unique identifier for j1939 compatible address claim | 0x1e (constant), 0x40 (constant), 0x90 (constant) | 0x1e (constant), 0x40 (constant), 0x90 (constant) | FALSE | FALSE
1839F380 | average thermistor value, checksum byte, fault bit in byte 5, highest thermistor id, highest thermistor value, lowest thermistor id, lowest thermistor value, thermistor module number, thermistors enabled count | average thermistor value, highest thermistor value, lowest thermistor value | average thermistor value, highest thermistor value, lowest thermistor value | FALSE | FALSE
1838F380 | current thermistor value, highest thermistor id, highest thermistor value, lowest thermistor id, lowest thermistor value, thermistor id relative to all configured modules, thermistor id relative to this module | current thermistor value, highest thermistor value, lowest thermistor value | current thermistor value, highest thermistor value, lowest thermistor value | FALSE | FALSE
80 | reserved for legacy equipment | reserved for legacy equipment | reserved for legacy equipment | FALSE | FALSE

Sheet: 1839_CRC_Check
1839F380 CRC Validation
Source | Line # | CAN ID | Length | Byte 1 | Byte 2 | Byte 3 | Byte 4 | Byte 5 | Byte 6 | Byte 7 | Byte 8 | Expected CRC | Actual CRC | CRC OK
MODULE | 167 | 1839F380 | 8 | 0x00 | 0x56 | 0xD7 | 0x00 | 0x80 | 0x00 | 0x00 | 0xEE | 0xEE | 0xEE | TRUE
MODULE | 234 | 1839F380 | 8 | 0x00 | 0x56 | 0xD7 | 0x00 | 0x80 | 0x00 | 0x00 | 0xEE | 0xEE | 0xEE | TRUE
MODULE | 299 | 1839F380 | 8 | 0x00 | 0x56 | 0xD7 | 0x00 | 0x80 | 0x00 | 0x00 | 0xEE | 0xEE | 0xEE | TRUE
MODULE | 371 | 1839F380 | 8 | 0x00 | 0x56 | 0xD7 | 0x00 | 0x80 | 0x00 | 0x00 | 0xEE | 0xEE | 0xEE | TRUE
MODULE | 436 | 1839F380 | 8 | 0x00 | 0x56 | 0xD7 | 0x00 | 0x80 | 0x00 | 0x00 | 0xEE | 0xEE | 0xEE | TRUE
MODULE | 506 | 1839F380 | 8 | 0x00 | 0x56 | 0xD7 | 0x00 | 0x80 | 0x00 | 0x00 | 0xEE | 0xEE | 0xEE | TRUE
MODULE | 576 | 1839F380 | 8 | 0x00 | 0x56 | 0xD7 | 0x00 | 0x80 | 0x00 | 0x00 | 0xEE | 0xEE | 0xEE | TRUE
MODULE | 646 | 1839F380 | 8 | 0x00 | 0x56 | 0xD7 | 0x00 | 0x80 | 0x00 | 0x00 | 0xEE | 0xEE | 0xEE | TRUE
MODULE | 711 | 1839F380 | 8 | 0x00 | 0x56 | 0xD7 | 0x00 | 0x80 | 0x00 | 0x00 | 0xEE | 0xEE | 0xEE | TRUE
MODULE | 781 | 1839F380 | 8 | 0x00 | 0x56 | 0xD7 | 0x00 | 0x80 | 0x00 | 0x00 | 0xEE | 0xEE | 0xEE | TRUE
MODULE | 849 | 1839F380 | 8 | 0x00 | 0x56 | 0xD7 | 0x00 | 0x80 | 0x00 | 0x00 | 0xEE | 0xEE | 0xEE | TRUE
MODULE | 920 | 1839F380 | 8 | 0x00 | 0x56 | 0xD7 | 0x00 | 0x80 | 0x00 | 0x00 | 0xEE | 0xEE | 0xEE | TRUE
MODULE | 986 | 1839F380 | 8 | 0x00 | 0x56 | 0xD7 | 0x00 | 0x80 | 0x00 | 0x00 | 0xEE | 0xEE | 0xEE | TRUE
MODULE | 1056 | 1839F380 | 8 | 0x00 | 0x56 | 0xD7 | 0x00 | 0x80 | 0x00 | 0x00 | 0xEE | 0xEE | 0xEE | TRUE
MODULE | 1124 | 1839F380 | 8 | 0x00 | 0x56 | 0xD7 | 0x00 | 0x80 | 0x00 | 0x00 | 0xEE | 0xEE | 0xEE | TRUE
MODULE | 1195 | 1839F380 | 8 | 0x00 | 0x56 | 0xD7 | 0x00 | 0x80 | 0x00 | 0x00 | 0xEE | 0xEE | 0xEE | TRUE
MODULE | 1261 | 1839F380 | 8 | 0x00 | 0x56 | 0xD7 | 0x00 | 0x80 | 0x00 | 0x00 | 0xEE | 0xEE | 0xEE | TRUE
MODULE | 1332 | 1839F380 | 8 | 0x00 | 0x56 | 0xD7 | 0x00 | 0x80 | 0x00 | 0x00 | 0xEE | 0xEE | 0xEE | TRUE
MODULE | 1395 | 1839F380 | 8 | 0x00 | 0x56 | 0xD7 | 0x00 | 0x80 | 0x00 | 0x00 | 0xEE | 0xEE | 0xEE | TRUE
MODULE | 1463 | 1839F380 | 8 | 0x00 | 0x56 | 0xD7 | 0x00 | 0x80 | 0x00 | 0x00 | 0xEE | 0xEE | 0xEE | TRUE
MODULE | 1528 | 1839F380 | 8 | 0x00 | 0x56 | 0xD7 | 0x00 | 0x80 | 0x00 | 0x00 | 0xEE | 0xEE | 0xEE | TRUE
MODULE | 1598 | 1839F380 | 8 | 0x00 | 0x56 | 0xD7 | 0x00 | 0x80 | 0x00 | 0x00 | 0xEE | 0xEE | 0xEE | TRUE
MODULE | 1664 | 1839F380 | 8 | 0x00 | 0x56 | 0xD7 | 0x00 | 0x80 | 0x00 | 0x00 | 0xEE | 0xEE | 0xEE | TRUE
MODULE | 1736 | 1839F380 | 8 | 0x00 | 0x56 | 0xD7 | 0x00 | 0x80 | 0x00 | 0x00 | 0xEE | 0xEE | 0xEE | TRUE
MODULE | 1803 | 1839F380 | 8 | 0x00 | 0x56 | 0xD7 | 0x00 | 0x80 | 0x00 | 0x00 | 0xEE | 0xEE | 0xEE | TRUE
MYCAN | 3 | 1839F380 | 8 | 0x00 | 0x3A | 0x54 | 0x43 | 0x0A | 0x00 | 0x08 | 0x24 | 0x24 | 0x24 | TRUE
MYCAN | 5 | 1839F380 | 8 | 0x00 | 0x39 | 0x54 | 0x42 | 0x0A | 0x00 | 0x08 | 0x22 | 0x22 | 0x22 | TRUE
MYCAN | 8 | 1839F380 | 8 | 0x00 | 0x3A | 0x54 | 0x43 | 0x0A | 0x00 | 0x08 | 0x24 | 0x24 | 0x24 | TRUE
MYCAN | 11 | 1839F380 | 8 | 0x00 | 0x3A | 0x54 | 0x43 | 0x0A | 0x00 | 0x08 | 0x24 | 0x24 | 0x24 | TRUE
MYCAN | 13 | 1839F380 | 8 | 0x00 | 0x3A | 0x54 | 0x43 | 0x0A | 0x00 | 0x08 | 0x24 | 0x24 | 0x24 | TRUE
MYCAN | 16 | 1839F380 | 8 | 0x00 | 0x3A | 0x54 | 0x43 | 0x0A | 0x00 | 0x08 | 0x24 | 0x24 | 0x24 | TRUE
MYCAN | 19 | 1839F380 | 8 | 0x00 | 0x3A | 0x54 | 0x43 | 0x0A | 0x00 | 0x08 | 0x24 | 0x24 | 0x24 | TRUE
MYCAN | 22 | 1839F380 | 8 | 0x00 | 0x3A | 0x54 | 0x42 | 0x0A | 0x00 | 0x08 | 0x23 | 0x23 | 0x23 | TRUE
MYCAN | 24 | 1839F380 | 8 | 0x00 | 0x3A | 0x54 | 0x43 | 0x0A | 0x00 | 0x08 | 0x24 | 0x24 | 0x24 | TRUE
MYCAN | 27 | 1839F380 | 8 | 0x00 | 0x3A | 0x54 | 0x43 | 0x0A | 0x00 | 0x08 | 0x24 | 0x24 | 0x24 | TRUE
MYCAN | 30 | 1839F380 | 8 | 0x00 | 0x3A | 0x54 | 0x43 | 0x0A | 0x00 | 0x08 | 0x24 | 0x24 | 0x24 | TRUE
MYCAN | 33 | 1839F380 | 8 | 0x00 | 0x3A | 0x54 | 0x43 | 0x0A | 0x00 | 0x08 | 0x24 | 0x24 | 0x24 | TRUE
MYCAN | 36 | 1839F380 | 8 | 0x00 | 0x3A | 0x54 | 0x43 | 0x0A | 0x00 | 0x08 | 0x24 | 0x24 | 0x24 | TRUE
MYCAN | 38 | 1839F380 | 8 | 0x00 | 0x3A | 0x54 | 0x43 | 0x0A | 0x00 | 0x08 | 0x24 | 0x24 | 0x24 | TRUE
MYCAN | 41 | 1839F380 | 8 | 0x00 | 0x3A | 0x54 | 0x43 | 0x0A | 0x00 | 0x08 | 0x24 | 0x24 | 0x24 | TRUE
MYCAN | 44 | 1839F380 | 8 | 0x00 | 0x3A | 0x54 | 0x43 | 0x0A | 0x00 | 0x08 | 0x24 | 0x24 | 0x24 | TRUE
MYCAN | 47 | 1839F380 | 8 | 0x00 | 0x3A | 0x54 | 0x43 | 0x0A | 0x00 | 0x08 | 0x24 | 0x24 | 0x24 | TRUE
MYCAN | 50 | 1839F380 | 8 | 0x00 | 0x3A | 0x54 | 0x43 | 0x0A | 0x00 | 0x08 | 0x24 | 0x24 | 0x24 | TRUE
MYCAN | 52 | 1839F380 | 8 | 0x00 | 0x3A | 0x54 | 0x43 | 0x0A | 0x00 | 0x08 | 0x24 | 0x24 | 0x24 | TRUE
MYCAN | 55 | 1839F380 | 8 | 0x00 | 0x3A | 0x54 | 0x43 | 0x0A | 0x00 | 0x08 | 0x24 | 0x24 | 0x24 | TRUE
MYCAN | 58 | 1839F380 | 8 | 0x00 | 0x3A | 0x54 | 0x43 | 0x0A | 0x00 | 0x08 | 0x24 | 0x24 | 0x24 | TRUE
MYCAN | 61 | 1839F380 | 8 | 0x00 | 0x3A | 0x54 | 0x43 | 0x0A | 0x00 | 0x08 | 0x24 | 0x24 | 0x24 | TRUE
MYCAN | 64 | 1839F380 | 8 | 0x00 | 0x3A | 0x54 | 0x43 | 0x0A | 0x00 | 0x08 | 0x24 | 0x24 | 0x24 | TRUE
MYCAN | 66 | 1839F380 | 8 | 0x00 | 0x3A | 0x54 | 0x43 | 0x0A | 0x00 | 0x08 | 0x24 | 0x24 | 0x24 | TRUE
MYCAN | 69 | 1839F380 | 8 | 0x00 | 0x3A | 0x54 | 0x43 | 0x0A | 0x00 | 0x08 | 0x24 | 0x24 | 0x24 | TRUE

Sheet: Interpretation
A / MODULE means the real thermistor module log.
B / MYCAN means the log from your implementation.
MISSING FROM MYCAN means the real module sends that CAN frame but your code did not.
For 1839F380, CRC OK means Byte 8 matched: (Byte1+...+Byte7+0x39+0x08) & 0xFF.
If 1839F380 matches but 18EEFF80 and 1838F380 are missing, then your implementation is only partially matching the module.
Header-column differences in Excel do not necessarily mean the CAN frame itself is wrong.

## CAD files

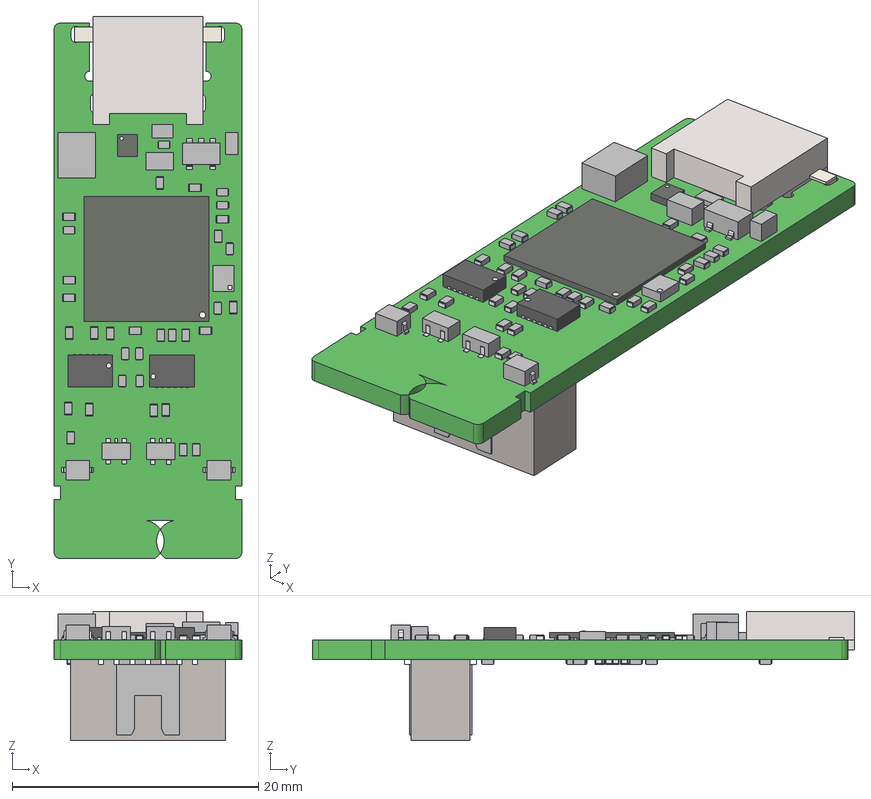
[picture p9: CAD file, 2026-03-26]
Docs/stlink-v3minie-3d-model/MB1762-V3MINIE-B01.step
15.2 x 44.0 x 10.5 mm
R0402 x 31
Extruded x 88
C0402 x 27
bigPin x 2
C0805_2012D
NX2016
C0603
_FTSH-107-01-L-DV-K_body
_FTSH-107-01-L-DV-K_pins1
_FTSH-107-01-L-DV-K_pins2
SOT323-5L x 2
User_Library-User_Library-DHVQFN_16-1 x 2
SOT23-5L
SOD323 x 2

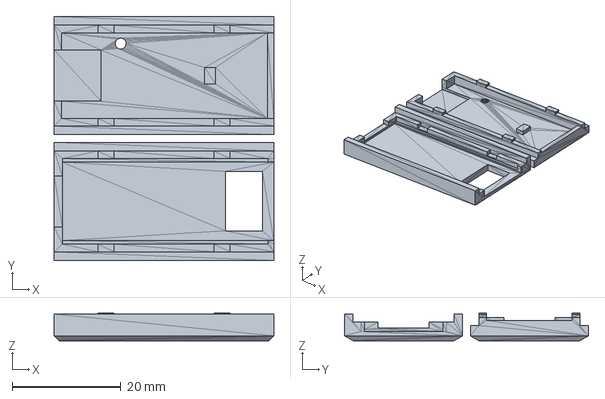
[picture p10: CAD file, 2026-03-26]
Docs/stlink-v3minie-casing-manufacturing/STLINK-V3MINIE-Box-V4.step
40.3 x 44.8 x 5.05 mm
STEP translator 7.5 1.1
STEP translator 7.5 1.2

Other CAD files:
TI_Ref_Code/bq79616_sample_code/Debug/source/sys_main.obj
TI_Ref_Code/bq79616_sample_code/Debug/source/sys_vim.obj
TI_Ref_Code/bq79616_sample_code/Debug/source/gio.obj
TI_Ref_Code/bq79616_sample_code/Debug/source/sys_phantom.obj
TI_Ref_Code/bq79616_sample_code/Debug/source/notification.obj
TI_Ref_Code/bq79616_sample_code/Debug/source/system.obj
TI_Ref_Code/bq79616_sample_code/Debug/source/sys_pcr.obj
TI_Ref_Code/bq79616_sample_code/Debug/source/esm.obj
TI_Ref_Code/bq79616_sample_code/Debug/source/rti.obj
TI_Ref_Code/bq79616_sample_code/Debug/source/sys_selftest.obj
TI_Ref_Code/bq79616_sample_code/Debug/source/sys_intvecs.obj
TI_Ref_Code/bq79616_sample_code/Debug/source/dabort.obj
TI_Ref_Code/bq79616_sample_code/Debug/source/sys_core.obj
TI_Ref_Code/bq79616_sample_code/Debug/source/sys_pmm.obj
TI_Ref_Code/bq79616_sample_code/Debug/source/sys_dma.obj
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

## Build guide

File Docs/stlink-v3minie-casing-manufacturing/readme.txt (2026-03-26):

******************************************************************************
* @file    readme.txt
* @author  MCD Application Team
* @version 2.0
* @date    22-September-2023
* @brief   STLINK-V3MINIE Casing manufacturing files package
******************************************************************************
* COPYRIGHT(c) 2023 STMicroelectronics
*
* The Open Platform License Agreement (“Agreement”) is a binding legal contract
* between you ("You") and STMicroelectronics International N.V. (“ST”), a
* company incorporated under the laws of the Netherlands acting for the purpose
* of this Agreement through its Swiss branch 39, Chemin du Champ des Filles,
* 1228 Plan-les-Ouates, Geneva, Switzerland.
*
* By using the enclosed reference designs, schematics, PC board layouts, and
* documentation, in hardcopy or CAD tool file format (collectively, the
* “Reference Material”), You are agreeing to be bound by the terms and
* conditions of this Agreement. Do not use the Reference Material until You
* have read and agreed to this Agreement terms and conditions. The use of
* the Reference Material automatically implies the acceptance of the Agreement
* terms and conditions.
*
* The complete Open Platform License Agreement can be found on www.st.com/opla.
******************************************************************************

========================
* 2.0 - 22-September-2023
========================
    + Replaced by STLINK-V3MINIE-Box-V4.stl and STLINK-V3MINIE-Box-V4.step compatible with MB1762B.
 
========================
* 1.0 - 11-May-2022 
========================
    + First official release containing STLINK-V3MINIE-Box-V3.stl.
  
******************* (C) COPYRIGHT 2023 STMicroelectronics *****END OF FILE

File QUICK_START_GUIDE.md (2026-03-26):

/*
 * ===========================================================================
 * BQ79616 WAKE-UP SEQUENCE DEBUGGING: QUICK START GUIDE
 * ===========================================================================
 *
 * Your problem: UART works but analog power won't turn on.
 * Root cause: The TX-low wake pulses likely aren't generating correctly.
 *
 * We've created comprehensive debugging tools and documentation.
 * Start here!
 *
 * ===========================================================================
 * FILES WE CREATED FOR YOU
 * ===========================================================================
 *
 * 1. src/bq79616_debug.c + include/bq79616_debug.h
 *    └─ Debug version of wake sequence with detailed logging
 *    └─ Tracks timing, GPIO states, UART status
 *    └─ Provides real-time feedback on what's failing
 *
 * 2. include/WAKE_DEBUGGING_GUIDE.h
 *    └─ Detailed step-by-step debugging procedure
 *    └─ Common failure modes and how to fix them
 *    └─ Hardware verification checklist
 *
 * 3. DEBUG_ACTION_PLAN.md (THIS FOLDER)
 *    └─ Concise 5-step action plan with expected values
 *    └─ What to look for in log output
 *    └─ How to interpret results
 *
 * 4. WAKE_TIMING_DIAGRAM.txt (THIS FOLDER)
 *    └─ ASCII timing diagram showing exactly what should happen
 *    └─ Millisecond-by-millisecond timeline
 *    └─ Visual reference to understand the sequence
 *
 * 5. REGISTER_REFERENCE.md (THIS FOLDER)
 *    └─ Explanation of BQ79616 registers involved in wake-up
 *    └─ Register bit layouts and what each bit does
 *    └─ How to read STATUS register to verify wake success
 *
 * ===========================================================================
 * WHAT WE MODIFIED IN YOUR CODE
 * ===========================================================================
 *
 * ✓ include/master.h
 *   └─ Added #include "bq79616_debug.h"
 *
 * ✓ src/main.c
 *   └─ Changed BQ_WakeSequence(1u) → BQ_WakeSequence_Debug(1u, &debug_info)
 *   └─ Added LOG_INFO calls to output debug data
 *
 * No other functional changes! All original code is preserved.
 *
 *
 * ===========================================================================
 * QUICK START: 5 MINUTES
 * ===========================================================================
 *
 * 1. BUILD & UPLOAD
 *    └─ Use PlatformIO: Build
 *    └─ Upload to board
 *    └─ Should compile with NO ERRORS
 *
 * 2. OPEN SERIAL MONITOR
 *    └─ Speed: 1,000,000 baud (or check your UART config)
 *    └─ Watch for log output starting with:
 *        "[INFO] === BQ79616 WAKE DEBUG START ==="
 *
 * 3. COPY OUTPUT TO DEBUG_ACTION_PLAN.md
 *    └─ Read STEP 1-5 in DEBUG_ACTION_PLAN.md
 *    └─ Compare your output to expected values
 *    └─ Find which step fails
 *
 * 4. APPLY FIX FOR FAILING STEP
 *    └─ See "FIX" section in that step
 *    └─ Make correction to code
 *    └─ Re-test
 *
 * 5. VERIFY SUCCESS
 *    └─ Look for: "Wake sequence RC: 0"
 *    └─ Look for: "SEND_WAKE RC: 0"
 *    └─ Analog power should now be ON!
 *
 *
 * ===========================================================================
 * EXPECTED LOG OUTPUT (HEALTHY WAKE SEQUENCE)
 * ===========================================================================
 *
 * [INFO] === BQ79616 WAKE DEBUG START ===
 * [INFO] TX pin initial state: 1
 * [INFO] Step 1: Disabling UART and converting TX to GPIO output
 * [INFO] Step 2: Sending WAKE pulse 1 (2.75 ms)
 * [INFO]   Pulse 1 width: 2750 us (expected ~2750 us)
 * [INFO]   TX pin state after pulse 1: 1
 * [INFO] Step 3: Waiting shutdown interval (3.5 ms)
 * [INFO] Step 4: Sending WAKE pulse 2 (2.75 ms)
 * [INFO]   Pulse 2 width: 2750 us (expected ~2750 us)
 * [INFO]   TX pin state after pulse 2: 1
 * [INFO] Step 5: Waiting for bridge ACTIVE state (3.5 ms)
 * [INFO] Step 6: Restoring UART functionality
 * [INFO]   UART reinitialized successfully
 * [INFO] Step 7: Sending CONTROL1[SEND_WAKE] command via UART
 * [INFO]   SEND_WAKE transmitted successfully
 * [INFO] Step 8: Waiting for stack propagation (11600 us for 1 device(s))
 * [INFO] TX pin final state: 1
 * [INFO] === BQ79616 WAKE DEBUG COMPLETE (rc=0) ===
 * [INFO] Wake sequence RC: 0
 * [INFO] Pulse 1 width: 2750 us
 * [INFO] Pulse 2 width: 2750 us
 * [INFO] SEND_WAKE RC: 0
 *
 * If your output matches this exactly → SUCCESS!
 * Analog power should be ON. Device is woken.
 *
 *
 * ===========================================================================
 * COMMON ISSUES & QUICK FIXES
 * ===========================================================================
 *
 * ISSUE #1: "Pulse width: 0 us" or "Pulse width: 1 us"
 * ─────────────────────────────────────────────────────
 * Cause: GPIO not working, pin not configured as output
 * Fix: Check GPIOC PIN 4 configuration in your GPIO setup
 *      Ensure it's set to GPIO_MODE_OUTPUT_PP (push-pull)
 * Test: Use oscilloscope on GPIOC PIN 4, should see pulses go LOW then HIGH
 *
 *
 * ISSUE #2: "TX pin state after pulse: 0" (stuck LOW)
 * ─────────────────────────────────────────────────────
 * Cause: GPIO.PIN_SET not working, pin stuck LOW
 * Fix: Check GPIO pull configuration, might have pull-down
 *      Verify GPIOC PIN 4 physically returns to HIGH
 * Test: Restart device, check if pin recovers in next cycle
 *       If never recovers, hardware problem (damaged pin, short to ground)
 *
 *
 * ISSUE #3: "Pulse width: 5500 us" (twice expected)
 * ─────────────────────────────────────────────────
 * Cause: SystemCoreClock value is wrong in code
 * Fix: Check actual MCU clock speed
 *      In SystemInit() or system file, verify:
 *      SystemCoreClock = 170000000  // STM32G4 typical
 * Test: Re-calibrate delay function using oscilloscope
 *
 *
 * ISSUE #4: "SEND_WAKE RC: -X" (write failed)
 * ──────────────────────────────────────────
 * Cause: Device not responding to UART (still SHUTDOWN)
 * Fix: Make sure ISSUE #1 and #2 are PASS first
 *      If pulses look good, check UART baud rate
 *      Default is 1,000,000 baud - verify your UART config
 * Test: Use logic analyzer on TX/RX lines during wake sequence
 *       Should see TX-low pulses, then UART traffic ~13ms later
 *
 *
 * ISSUE #5: All tests pass but analog power still OFF
 * ─────────────────────────────────────────────────────
 * Cause: Different BQ79616 revision, different control bit
 * Fix: Check your BQ79616 datasheet for:
 *      - CONTROL1 register bit layout (may not be bit 5 for SEND_WAKE)
 *      - STATUS register ACTIVE bit location
 *      - Any additional setup registers needed
 * Test: Read STATUS register after wake, check if ACTIVE bit is set
 *       Look at register values via DEBUG_ACTION_PLAN.md Step 5
 *
 *
 * ===========================================================================
 * WHERE TO GET HELP
 * ===========================================================================
 *
 * 1. Read WAKE_DEBUGGING_GUIDE.h for detailed step-by-step procedure
 *
 * 2. Check WAKE_TIMING_DIAGRAM.txt for visual reference
 *
 * 3. Consult REGISTER_REFERENCE.md for register details
 *
 * 4. Review DEBUG_ACTION_PLAN.md for checklist approach
 *
 * 5. Compare log output to EXPECTED LOG OUTPUT above
 *
 * 6. Use oscilloscope on GPIOC PIN 4 and TX/RX lines to verify
 *    hardware-level behavior
 *
 * 7. Check BQ79616 datasheet for:
 *    - UART protocol details
 *    - Register definitions for your specific revision
 *    - Wake sequence timing requirements
 *    - Power state transition diagrams
 *
 *
 * ===========================================================================
 * HARDWARE VERIFICATION FIRST!
 * ===========================================================================
 *
 * Before debugging code, verify hardware is correct:
 *
 * CHECKLIST:
 * ☐ GPIOC PIN 4 is physically connected to BQ79616 RXD pin
 * ☐ GPIOC PIN 5 (or your RX) connected to BQ79616 TXD pin  
 * ☐ Common GND between MCU and BQ79616
 * ☐ BQ79616 power supply is connected and stable (check voltage)
 * ☐ UART baud rate matches BQ79616 (1,000,000 typical)
 * ☐ No level shifters OR they're configured correctly
 * ☐ Oscilloscope probes connected to verify signals
 *
 * If any of these are wrong, no amount of code debugging will help!
 *
 *
 * ===========================================================================
 * NEXT STEPS
 * ===========================================================================
 *
 * 1. Build your code now (no changes needed, already updated)
 * 2. Watch serial monitor for debug output
 * 3. Open DEBUG_ACTION_PLAN.md and follow Step 1-5
 * 4. Report back with the exact log output you see
 * 5. I'll help you interpret and fix any failures
 *
 * ===========================================================================
 */

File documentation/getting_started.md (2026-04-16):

# Getting Started

This is the shortest path to get a new board from unknown state to running firmware with logs and CAN traffic.

## 1) Install tools

- PlatformIO CLI/IDE (build + upload)
- STM32CubeProgrammer (option bytes, low-level flash recovery)
- Serial terminal (`pio device monitor` is enough)
- CAN capture tool used by the team (Orion BMS)

See: `reference/toolchain_and_programmer_reference.md`

## 2) Gather hardware

- Target board with STM32G474 MCU
- STLINK-V3MINIE probe
- USB cable for STLINK
- External target power supply
- CAN bus connection to your logger/BMS bench network

> STLINK-V3MINIE is a debug/programming probe and VCP bridge; it does not power the target application.

## 3) Verify pinout and wiring

Before first flash, validate wiring against:

- `pinout_and_signals.md`
- `hardware_setup.md`

## 4) Fresh-chip bring-up first

For brand-new chips/boards, complete programmer setup before normal flashing:

- Review boot option bytes (`nSWBOOT0` / `nBOOT0`)
- Apply project reset/debug setting: **NRST Level 3**

See: `startup_and_flashing.md#fresh-chip--brand-new-board-bring-up`

## 5) Build and flash

```bash
pio run -e nucleo_g474re
pio run -e nucleo_g474re -t upload
```

## 6) Verify first boot

```bash
pio device monitor -b 115200
```

Expected checks:

- One-time startup LED pulse
- UART logs on STLINK VCP
- CAN IDs `0x18EEFF80`, `0x1839F380`, `0x1838F380`

## 7) If anything fails

Go directly to:

- `troubleshooting.md`
- `known_issues_and_resolutions.md`
- `bringup_checklist.md`
- `reference/chip_inventory.md`

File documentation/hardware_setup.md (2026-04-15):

# Hardware Setup

This section focuses on practical bench bring-up for the current firmware and pin mappings in code.

## Required boards and tools

| Item | Purpose | Source in repo |
|---|---|---|
| STM32G474 target board | Runs firmware | `platformio.ini`, `src/*` |
| STLINK-V3MINIE | SWD programming/debug + VCP logs | `Docs/um2910-stlinkv3minie-*.pdf` |
| External target power | Powers the target board/application | STLINK note in `Docs/um2910-*.pdf` |
| CAN interface + bus wiring | Observe CAN traffic | `src/can.c`, `src/can_messages.c` |
| BQ chain hardware | External voltage monitor path | `src/bq79616.c` |

For full component context (including CAN transceiver and legacy/reference chips), see `reference/chip_inventory.md`.

## Wiring and interface overview

- SWD/programmer: SWDIO, SWCLK, NRST, GND, target reference voltage
- Logging UART: USART2 `PA2/PA3` via STLINK VCP, 115200 baud
- BQ transport UART: USART1 `PC4/PC5` at 1,000,000 baud
- CAN: FDCAN1 `PA11` (RX) and `PA12` (TX)
- Thermistors: ADC1 channels mapped in `src/therm.c`

Detailed signal tables are in `pinout_and_signals.md`.

## Power and connection order

1. Connect STLINK-V3MINIE SWD to target.
2. Connect USB to STLINK (debug + VCP).
3. Apply external target power.
4. Open CubeProgrammer or PlatformIO tools.

> STLINK-V3MINIE does not power the target application. Always power the board separately.

## ST-Link / debugger usage notes

- Probe: STLINK-V3MINIE
- Interface: SWD
- Keep NRST connected for reliable reset/programming sequences
- For first-time bring-up, apply project setup in `startup_and_flashing.md`

## Before you power on (checklist)

- [ ] SWD wiring correct (including NRST and GND)
- [ ] External target power connected and stable
- [ ] CAN wiring and termination match your bench setup
- [ ] BQ UART lines (`PC4` TX, `PC5` RX) connected to battery-monitor chain
- [ ] No accidental shorts on ADC thermistor inputs

## First power-on expected behavior

- LEDs initialize and all pulse once (`LED_All_Pulse(1000u)`)
- UART log channel becomes active (USART2)
- Firmware performs blocking BQ startup gate
- CAN scheduling starts after BQ startup reaches READY or FAILED terminal state

See also:

- `pinout_and_signals.md`
- `startup_and_flashing.md`
- `logging_and_leds.md`
- `bringup_checklist.md`

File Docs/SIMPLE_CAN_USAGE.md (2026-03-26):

# Simple CAN Message Usage

## Overview

Instead of dealing with structs and complex encoders, use these 3 simple functions:

```c
CAN_Msg_SendClaim_Simple()      // J1939 Address Claim
CAN_Msg_SendBMS_Simple()        // BMS Broadcast
CAN_Msg_SendGeneral_Simple()    // General Broadcast (cycle through thermistors)
```

---

## Example Usage in `can.c`

```c
void CAN_App_Send_Transmission(can_app_ctx_t *ctx)
{
    const uint32_t now = HAL_GetTick();
    uint8_t payload[8];
    
    // Read your ADC values (you need to implement this)
    uint16_t adc_values[10];
    ADC_ReadAllThermistors(adc_values);  // Your function
    
    /* ===== MESSAGE 1: J1939 Address Claim (every 200ms) ===== */
    if ((now - ctx->last_claim_ms) >= 200) {
        uint32_t can_id = CAN_Msg_SendClaim_Simple(payload);
        CAN_Comm_SendExt(can_id, payload, 8);
        ctx->last_claim_ms = now;
    }
    
    /* ===== MESSAGE 2: BMS Broadcast (every 100ms) ===== */
    if ((now - ctx->last_bms_ms) >= 100) {
        uint32_t can_id = CAN_Msg_SendBMS_Simple(adc_values, 10, payload);
        CAN_Comm_SendExt(can_id, payload, 8);
        ctx->last_bms_ms = now;
    }
    
    /* ===== MESSAGE 3: General Broadcast (every 100ms, rotating) ===== */
    if ((now - ctx->last_general_ms) >= 100) {
        uint32_t can_id = CAN_Msg_SendGeneral_Simple(adc_values, 10, ctx->thermistor_index, payload);
        CAN_Comm_SendExt(can_id, payload, 8);
        
        // Cycle to next thermistor (0-9, then loop)
        ctx->thermistor_index = (ctx->thermistor_index + 1) % 10;
        ctx->last_general_ms = now;
    }
}
```

---

## What Each Function Does

### 1. `CAN_Msg_SendClaim_Simple(payload)`

**What it sends**: "I'm Module 0, I exist on the bus"

**Frequency**: Every 200ms

**Returns**: CAN ID `0x18EEFF80`

**Payload**:
```
F3 00 80 F3 00 40 1E 90
```

**Usage**:
```c
uint8_t payload[8];
uint32_t can_id = CAN_Msg_SendClaim_Simple(payload);
CAN_Comm_SendExt(can_id, payload, 8);
```

---

### 2. `CAN_Msg_SendBMS_Simple(adc_values, num_thermistors, payload)`

**What it sends**: Summary of all thermistors (count, min, max, average)

**Frequency**: Every 100ms

**Returns**: CAN ID `0x1839F380`

**Payload**:
```
[0] Number of thermistors (10)
[1] Lowest temperature
[2] Highest temperature
[3] Average temperature
[4] Lowest thermistor ID
[5] Highest thermistor ID
[6] Lowest ID (always 0 for Module 0)
[7] Checksum
```

**Usage**:
```c
uint16_t adc_values[10] = { 2048, 2100, 1950, ... };  // Your ADC readings
uint8_t payload[8];
uint32_t can_id = CAN_Msg_SendBMS_Simple(adc_values, 10, payload);
CAN_Comm_SendExt(can_id, payload, 8);
```

---

### 3. `CAN_Msg_SendGeneral_Simple(adc_values, num_thermistors, thermistor_id, payload)`

**What it sends**: Individual thermistor temperature (one at a time)

**Frequency**: Every 100ms (cycle through 0-9)

**Returns**: CAN ID `0x183BF380`

**Payload**:
```
[0] Thermistor ID (0-9)
[1] This thermistor's temperature
[2] Thermistor ID relative to module
[3] Lowest temperature (across all)
[4] Highest temperature (across all)
[5] Highest thermistor ID
[6] Lowest thermistor ID
[7] Checksum
```

**Usage** (in a loop):
```c
static uint8_t current_thermistor = 0;

uint8_t payload[8];
uint32_t can_id = CAN_Msg_SendGeneral_Simple(adc_values, 10, current_thermistor, payload);
CAN_Comm_SendExt(can_id, payload, 8);

// Next thermistor for next time
current_thermistor = (current_thermistor + 1) % 10;
```

---

## Complete Example

```c
#include "can_messages.h"
#include "can.h"
#include "adc.h"

static uint8_t thermistor_index = 0;
static uint32_t last_claim_ms = 0;
static uint32_t last_bms_ms = 0;
static uint32_t last_general_ms = 0;

void CAN_SendAllMessages(void)
{
    uint32_t now = HAL_GetTick();
    uint8_t payload[8];
    
    // Get ADC readings
    uint16_t adc_values[10];
    ADC_ReadAllThermistors(adc_values);
    
    // 1. Address Claim (every 200ms)
    if ((now - last_claim_ms) >= 200) {
        uint32_t id = CAN_Msg_SendClaim_Simple(payload);
        CAN_Comm_SendExt(id, payload, 8);
        last_claim_ms = now;
    }
    
    // 2. BMS Broadcast (every 100ms)
    if ((now - last_bms_ms) >= 100) {
        uint32_t id = CAN_Msg_SendBMS_Simple(adc_values, 10, payload);
        CAN_Comm_SendExt(id, payload, 8);
        last_bms_ms = now;
    }
    
    // 3. General Broadcast (every 100ms, rotating)
    if ((now - last_general_ms) >= 100) {
        uint32_t id = CAN_Msg_SendGeneral_Simple(adc_values, 10, thermistor_index, payload);
        CAN_Comm_SendExt(id, payload, 8);
        
        thermistor_index = (thermistor_index + 1) % 10;
        last_general_ms = now;
    }
}
```

---

## That's It!

**No structs. No complexity. Just 3 functions.**

The old complex functions still exist for testing, but you don't need to use them.

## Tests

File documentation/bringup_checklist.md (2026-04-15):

# Bringup Checklist

Use this linearly for first-time board bring-up and after major hardware/flash changes.

- [ ] Hardware connected (SWD, UART, CAN, BQ links)
- [ ] Board powered from external supply (not probe-only)
- [ ] Debugger connected and stable (STLINK SWD + NRST)
- [ ] Option bytes checked in CubeProgrammer (`nSWBOOT0` / `nBOOT0` path)
- [ ] NRST Level 3 checked/applied for this project
- [ ] Firmware built and flashed successfully
- [ ] Full power cycle performed after flashing/option-byte update
- [ ] UART logs verified at `115200`
- [ ] LEDs checked for expected startup and no persistent fault indication
- [ ] CAN communication verified (`0x18EEFF80`, `0x1839F380`, `0x1838F380`)
- [ ] BQ chain behavior verified (no persistent keep-alive/fault-poll failures)

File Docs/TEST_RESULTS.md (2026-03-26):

# CAN Message Testing - Clean & Focused

## Summary
✅ **ALL 7 TESTS PASSING**

Tests focus on the **simple helper functions** - no complexity, just testing what matters!

---

## Test Coverage

### ✅ TEST 1: ADC Conversion with Proper Rounding
- **Tests**: `CAN_Msg_ADCToTemp()`
- **What it checks**:
  - Rounding works correctly (ADC 2088 → 51°C, not 50°C)
  - Boundary values (ADC 0 = 0°C, ADC 4095 = 100°C)
- **Result**: PASS ✓

### ✅ TEST 2: Address Claim
- **Tests**: `CAN_Msg_SendClaim_Simple()`
- **What it checks**:
  - CAN ID is 0x18EEFF80
  - All 8 payload bytes match specification
- **Result**: PASS ✓

### ✅ TEST 3: BMS Broadcast - Min/Max/Average
- **Tests**: `CAN_Msg_SendBMS_Simple()`
- **What it checks**:
  - Correctly finds minimum temperature (10°C at ID 9)
  - Correctly finds maximum temperature (100°C at ID 8)
  - Correctly calculates average (55°C)
  - CAN ID is 0x1839F380
  - Payload has 10 thermistors
- **Result**: PASS ✓

### ✅ TEST 4: General Broadcast - Thermistor 0
- **Tests**: `CAN_Msg_SendGeneral_Simple()`
- **What it checks**:
  - Thermistor ID 0 (FIRST thermistor, not 1!)
  - Reports correct temperature
  - CAN ID is 0x183BF380
- **Result**: PASS ✓

### ✅ TEST 5: General Broadcast - Thermistor 9
- **Tests**: `CAN_Msg_SendGeneral_Simple()`
- **What it checks**:
  - Thermistor ID 9 (LAST thermistor, not 10!)
  - Reports correct temperature (100°C)
  - System min/max calculated across all thermistors
- **Result**: PASS ✓

### ✅ TEST 6: BMS Broadcast - All Same Temperature
- **Tests**: `CAN_Msg_SendBMS_Simple()`
- **What it checks**:
  - Edge case: all 10 thermistors at 25°C
  - Min = Max = Avg = 25°C
- **Result**: PASS ✓

### ✅ TEST 7: Checksum Calculation
- **Tests**: Checksum in `CAN_Msg_SendBMS_Simple()`
- **What it checks**:
  - Manual calculation matches function output
  - Formula: PGN (0x39) + DLC (8) + sum(payload[0..6])
- **Result**: PASS ✓

---

## Key Clarifications

### Thermistor IDs are 0-9, NOT 1-10!
- You have 10 thermistors numbered **0 through 9**
- Thermistor 0 = **first** thermistor
- Thermistor 9 = **last** thermistor

### What Each Function Tests

**`CAN_Msg_SendClaim_Simple()`**
- Returns: CAN ID 0x18EEFF80
- Payload: Fixed 8 bytes (F3 00 80 F3 00 40 1E 90)
- Purpose: Announces Module 0 presence

**`CAN_Msg_SendBMS_Simple()`**
- Returns: CAN ID 0x1839F380
- Payload: Count, Min, Max, Avg, Min ID, Max ID, Lowest ID, Checksum
- Purpose: Summary of all thermistors

**`CAN_Msg_SendGeneral_Simple()`**
- Returns: CAN ID 0x183BF380
- Payload: Thermistor ID (0-9), This temp, Relative ID, Min, Max, Max ID, Min ID, Checksum
- Purpose: Individual thermistor report (cycle through 0-9)

---

## Running the Tests

```bash
# Run all tests
pio test -e native -v

# Expected output:
# [  PASSED  ] 7 tests
```

---

## What's NOT Tested (Yet)

1. ❌ Error handling (disconnected thermistor, short circuit)
2. ❌ Fault byte (0x80) when sensor fails
3. ❌ Steinhart-Hart equation (still using placeholder linear conversion)
4. ❌ Integration with actual can.c code
5. ❌ Timing (200ms claim, 100ms broadcasts)

---

## Test Output Example

```
TEST 3: BMS Broadcast - Min/Max/Avg
  CAN ID: 0x1839F380 (expected 0x1839F380)
  Count: 10 thermistors
  Min:   10°C (ID 9)
  Max:   100°C (ID 8)
  Avg:   55°C
  PASS - Min/Max/Avg correct
```

Clean, simple, to-the-point. ✓

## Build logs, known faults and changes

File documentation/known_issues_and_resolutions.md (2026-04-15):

# Known Issues and Resolutions

This section tracks observed project issues from repository notes, code comments, and bring-up behavior.

## 1) SWBOOT / boot option-byte bring-up issue

- Title: Boot option-byte mismatch causes inconsistent boot behavior
- Where it appeared: Bring-up workflow and programmer setup
- Symptoms:
  - Firmware behavior differs between reflash/reset and cold power cycle
  - Board may appear stuck in bootloader-like behavior
  - Runtime reliability improves only after reprogramming
- Root cause:
  - Project evidence indicates boot option-byte configuration (`nSWBOOT0` / `nBOOT0` BOOT path) must be set correctly during first-time setup
  - Exact board-specific profile must be verified in programmer option-byte view
- Solution:
  1. Connect with CubeProgrammer
  2. Read and set boot option-byte profile to project known-good values
  3. Reprogram option bytes and power-cycle
- Note for future developers:
  - Treat this as a required fresh-chip setup step
  - Verify against schematic and board docs in `Docs/` when uncertain

## 2) NRST Level 3 required for reliable bring-up (project-specific)

- Title: Reset/programming reliability depends on NRST Level 3 in this project
- Where it appeared: Flash/debug setup during bring-up
- Symptoms:
  - Unreliable programming/debug resets until reset mode changed
- Root cause:
  - Exact electrical reason is not proven in-code; observed behavior is repeatable in team bring-up
- Solution:
  - Use NRST Level 3 during flashing/setup for this project
- Note for future developers:
  - Keep this as a project setting, not a universal STM32 recommendation

## 3) CAN timing drift due to timer/loop interaction

- Title: TIM7 and blocking reads caused CAN transmit interval errors
- Where it appeared: `Docs/CAN_TIMING_ISSUE_AND_FIX.md`
- Symptoms:
  - Messages expected at 100/200 ms appeared around ~2 s cadence
- Root cause:
  - TIM7 setup/IRQ wiring mismatch plus long blocking BQ fault reads in loop
- Solution:
  - Correct TIM7 period/IRQ path and reduce blocking read impact
- Note for future developers:
  - Keep ISR lightweight and avoid long blocking operations in service loop paths that gate CAN send timing

## 4) Documentation drift in legacy notes

- Title: Some older markdown does not match current code
- Where it appeared: root `README.md`, portions of `Docs/*.md`
- Symptoms:
  - references to old architecture/IDs/peripherals
- Root cause:
  - docs evolved separately from current implementation
- Solution:
  - use `src/` + `include/` as source of truth and maintain this `documentation/` set
- Note for future developers:
  - update docs together with firmware changes that alter startup, comms, IDs, or pins

See also:

- `startup_and_flashing.md`
- `troubleshooting.md`

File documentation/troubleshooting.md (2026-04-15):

# Troubleshooting

Use this by symptom. Each section gives likely cause, verification method, and fix.

## Cannot flash firmware

- Symptom: Programmer fails to erase/program or verify.
- Likely cause: SWD wiring/power issue, target held in bad boot/reset state.
- How to verify: CubeProgrammer cannot read device info reliably.
- Fix: Check power and SWD pins, use mass erase, then run fresh-chip bring-up steps.

## Debugger cannot connect

- Symptom: STLINK sees no target or unstable connection.
- Likely cause: Missing VREF/GND/NRST, wrong reset mode, unstable power.
- How to verify: intermittent connect/disconnect or ID read failures.
- Fix: Rewire SWD fully, set project reset mode to NRST Level 3, power-cycle target.

## No logs on serial console

- Symptom: `pio device monitor` shows no startup output.
- Likely cause: wrong COM port/baud, no target power, firmware not reaching UART init.
- How to verify: check `115200`, STLINK VCP enumeration, and power rails.
- Fix: correct monitor settings, power target, then reflash and retry.

## Code only works after reprogramming

- Symptom: runs after flash/debug reset, fails after cold power cycle.
- Likely cause: boot option-byte mismatch (`nSWBOOT0`/`nBOOT0`) or reset setup mismatch.
- How to verify: compare behavior between debug reset and cold boot.
- Fix: re-apply CubeProgrammer boot option-byte profile and set NRST Level 3.

## Power issue

- Symptom: random resets, unstable comms, no consistent boot.
- Likely cause: STLINK assumed to power target, or bench supply instability.
- How to verify: measure target rails during flash and runtime.
- Fix: provide stable external power; do not rely on STLINK for target application power.

## Communication issue (CAN)

- Symptom: no expected CAN IDs on bus.
- Likely cause: bus wiring/termination, scheduling disabled, or FDCAN init/runtime fault.
- How to verify: check for IDs `0x18EEFF80`, `0x1839F380`, `0x1838F380`; inspect logs.
- Fix: validate wiring/termination, verify startup reached CAN enabled state.

## Battery monitor chain not responding

- Symptom: BQ keep-alive/fault poll errors and voltage path disabled.
- Likely cause: UART wiring (`PC4/PC5`), wake sequence failure, BQ power/path issue.
- How to verify: check BQ logs and fault register read outcomes.
- Fix: verify BQ UART wiring/power, rerun startup, inspect `src/bq79616.c` wake path.

## Boot/reset misconfiguration

- Symptom: inconsistent startup, bootloader-like behavior, or poor debug reset behavior.
- Likely cause: option-byte boot config not matching project needs; reset mode mismatch.
- How to verify: read option bytes in CubeProgrammer and compare against known-good profile.
- Fix: set boot option bytes for user-flash boot path and set NRST Level 3 for this project.

See also:

- `startup_and_flashing.md`
- `known_issues_and_resolutions.md`
- `bringup_checklist.md`

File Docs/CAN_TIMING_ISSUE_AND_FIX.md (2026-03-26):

# CAN Timing Issue and Fix

## Summary

The CAN transmit timing bug had two separate causes:

1. The dedicated CAN timer (`TIM7`) was not configured as a true `100 ms` hardware timer.
2. The main loop was being blocked for about `2 seconds` by debug fault reads to the BQ device, which made correctly-timed CAN flags get serviced very late.

Because of that combination, CAN traffic did not appear at the intended rates:

- J1939 claim should be every `200 ms`
- BMS broadcast should be every `100 ms`
- General broadcast should be every `100 ms`

Instead, logs showed intervals such as:

```text
[DEBUG] TX 0x18EEFF80 claim interval=2094ms result=0
[DEBUG] TX 0x1839F380 bms interval=2094ms result=0 ...
[DEBUG] TX 0x1838F380 gen interval=2094ms result=0 ...
```

That `2094 ms` value was not the timer period itself. It was the amount of time the main loop was stalled before it came back and finally serviced the pending CAN flags.

---

## What the Issue Was

### Issue 1: `TIM7` was not a real `100 ms` CAN timer

The code originally treated `TIM7` like this:

- `TIMER7_CLK_HZ = 10000`
- `TIMER7_PERIOD = 100`

That means:

- timer tick = `0.1 ms`
- period = `100 counts`
- interrupt every `10 ms`

So `TIM7` was actually firing every `10 ms`, not every `100 ms`.

The old design then used software counters:

- `CAN_TICKS_FOR_100MS = 10`
- `CAN_TICKS_FOR_200MS = 20`

That can work in principle, but it was not what was intended when the goal was a separate CAN timer that directly supports `100 ms` and `200 ms` scheduling.

### Issue 2: `TIM7` interrupt wiring was incomplete

On the STM32G474, `TIM7` does not use `TIM7_IRQn`.
It shares the interrupt vector with DAC and uses:

- `TIM7_DAC_IRQn`
- `TIM7_DAC_IRQHandler`

The project initially had the wrong interrupt hookup for `TIM7`, so the dedicated CAN timer path was not fully connected to the MCU's actual vector table.

### Issue 3: Main loop was blocked by BQ fault reads

After fixing the timer path, the log still showed about `2094 ms` intervals. That turned out to be a different problem.

In `main.c`, the loop did this every `200 ms`:

- read `FAULT_SYS`
- read `FAULT_COMM1`

Both calls used `bq79616_read()`, and that wrapper used a hard-coded `1000 ms` timeout.

So when the BQ read did not return immediately, the loop could block for:

- `1000 ms` on the first read
- `1000 ms` on the second read
- total about `2000 ms`

That lines up almost exactly with the observed `2094 ms`.

Since `CAN_SendMessages()` runs in the main loop, not inside the interrupt, the CAN timer flags were set on time by the ISR but were not consumed until the main loop came back.

That is why all three message intervals looked late by the same amount.

---

## How We Fixed It

### Fix 1: Make `TIM7` a real `100 ms` hardware timer

`TIM7` was changed to use:

- `TIMER7_CLK_HZ = 10000`
- `TIMER7_PERIOD = 1000`

Math:

- `10000 Hz` timer clock = `0.1 ms` per count
- `1000 counts` = `100 ms` per interrupt

Then the CAN timing flags became:

- `CAN_TICKS_FOR_100MS = 1`
- `CAN_TICKS_FOR_200MS = 2`

So now:

- every `TIM7` interrupt = `100 ms`
- every second `TIM7` interrupt = `200 ms`

This is simpler and matches the intended behavior.

### Fix 2: Use the correct STM32G474 `TIM7` interrupt

The dedicated CAN timer now uses:

- `HAL_NVIC_SetPriority(TIM7_DAC_IRQn, ...)`
- `HAL_NVIC_EnableIRQ(TIM7_DAC_IRQn)`
- `TIM7_DAC_IRQHandler()`

This matches the STM32G474 startup vector and ensures `HAL_TIM_IRQHandler(&g_htim7)` is actually called.

### Fix 3: Sto p the BQ fault reads from stalling the loop

A new helper was added:

```c
int bq79616_read_timeout(..., uint32_t timeout_ms);
```

Then the periodic fault-check reads in `main.c` were changed to use a short timeout:

- `BQ_FAULT_READ_TIMEOUT_MS = 10`

Instead of waiting up to `1000 ms` per read, each debug fault read now gives up quickly if the device does not answer.

This keeps the main loop responsive so `CAN_SendMessages()` can run often enough to service `100 ms` and `200 ms` flags on time.

### Fix 4: Remove noisy keep-alive success spam

The loop was printing:

```text
[DEBUG] Keep-alive write OK (0x21)
```

every `20 ms`.

That output was removed for successful writes and kept only for failures. This reduces UART spam and makes CAN timing logs easier to see.

---

## Why the Fix Works

### Why the timer fix works

The CAN scheduler now has a dedicated timer whose base interrupt period is already `100 ms`.

That means the logic is straightforward:

- one interrupt -> set `100 ms` flag
- two interrupts -> set `200 ms` flag

There is no longer a `10 ms` base period on `TIM7` that must be divided by `10` in software just to reach the intended CAN timing.

### Why the interrupt fix works

Even correct timer register values do nothing if the MCU never enters the interrupt handler.

Using the real STM32G474 vector names fixes that path end-to-end:

- timer update event occurs
- NVIC sees `TIM7_DAC_IRQn`
- `TIM7_DAC_IRQHandler()` runs
- HAL dispatches to `HAL_TIM_PeriodElapsedCallback()`
- CAN flags are set

### Why the BQ timeout fix works

The CAN send path is not interrupt-driven all the way through.

The interrupt only sets flags.
Actual CAN message transmission still happens in the main loop.

So if the main loop blocks for `~2 seconds`, CAN messages will also appear `~2 seconds` late even when the timer ISR is correct.

By shortening the debug fault-read timeout from `1000 ms` to `10 ms`, the loop is no longer monopolized by those reads, and the CAN transmit service can run at the expected cadence.

---

## Files Changed

- `include/timer.h`
- `src/timer.c`
- `src/stm32g4xx_it.c`
- `include/bq79616.h`
- `src/bq79616.c`
- `src/main.c`

---

## Expected Behavior After the Fix

After flashing the updated firmware:

- claim message interval should be about `200 ms`
- BMS broadcast interval should be about `100 ms`
- general broadcast interval should be about `100 ms`

The CAN logs are still rate-limited for readability, so you may not see a log line on every single transmit event, but the `interval=` values should now be near the intended timing instead of `2094 ms`.

---

## Verification

Build verification completed successfully:

```bash
pio run
```

Expected runtime checks:

1. Boot the board and watch the console.
2. Confirm `TIM7 (CAN-DEDICATED)` initialization reports a `100 ms` interrupt period.
3. Confirm CAN debug lines report intervals near `100 ms` and `200 ms`.
4. Confirm the old `2094 ms` pattern does not return unless the main loop becomes blocked again.

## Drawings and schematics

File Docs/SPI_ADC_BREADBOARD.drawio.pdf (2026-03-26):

+

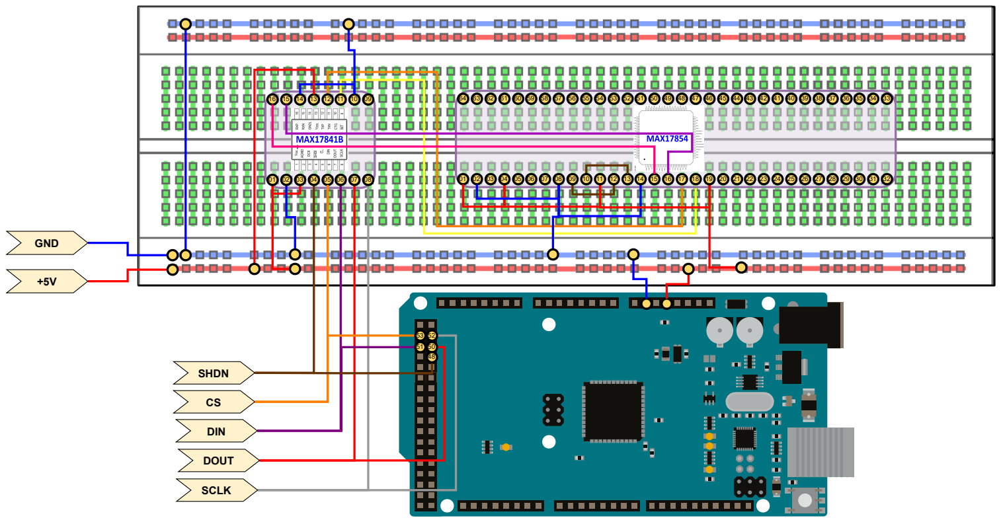
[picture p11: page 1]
GND; SHDN; SCLK; DIN; DOUT

53 | 52
51 | 50
48

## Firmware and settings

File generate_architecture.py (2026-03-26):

#!/usr/bin/env python3
"""
Auto-generate Mermaid architecture diagram from STM32 codebase
Usage: python3 generate_architecture.py
"""

import os
import re
from pathlib import Path
from collections import defaultdict

class CodebaseAnalyzer:
    def __init__(self, root_dir):
        self.root = Path(root_dir)
        self.files = {'src': [], 'include': [], 'docs': []}
        self.includes = defaultdict(set)
        self.functions = defaultdict(list)
        self.function_calls = defaultdict(set)
        self.globals = defaultdict(list)
        
    def scan_files(self):
        """Scan all C/H files"""
        for folder in ['src', 'include']:
            path = self.root / folder
            if path.exists():
                for file in list(path.glob('*.c')) + list(path.glob('*.h')):
                    self.files[folder].append(file)
                    
    def parse_includes(self, filepath):
        """Extract #include statements"""
        try:
            with open(filepath, 'r', encoding='utf-8') as f:
                content = f.read()
                includes = re.findall(r'#include\s+"([^"]+)"', content)
                return set(includes)
        except:
            return set()
            
    def parse_functions(self, filepath):
        """Extract function definitions"""
        try:
            with open(filepath, 'r', encoding='utf-8') as f:
                content = f.read()
                # Remove comments
                content = re.sub(r'/\*.*?\*/', '', content, flags=re.DOTALL)
                content = re.sub(r'//.*?\n', '\n', content)
                # Find functions
                funcs = re.findall(r'\n(\w+\s+\**\s*\w+)\s*\([^)]*\)\s*\{', content)
                return [f.strip().split()[-1] for f in funcs]
        except:
            return []
            
    def parse_function_calls(self, filepath):
        """Extract function calls"""
        try:
            with open(filepath, 'r', encoding='utf-8') as f:
                content = f.read()
                # Remove comments
                content = re.sub(r'/\*.*?\*/', '', content, flags=re.DOTALL)
                content = re.sub(r'//.*?\n', '\n', content)
                # Find function calls
                calls = re.findall(r'(\w+)\s*\(', content)
                return set(calls)
        except:
            return set()
            
    def parse_globals(self, filepath):
        """Extract global variables"""
        try:
            with open(filepath, 'r', encoding='utf-8') as f:
                content = f.read()
                # Look for globals like g_*, UART_*, ADC_*, etc
                globs = re.findall(r'\n((?:extern\s+)?[\w\s\*]+\s+[g_]\w+)\s*[;=]', content)
                globs += re.findall(r'\n((?:UART|ADC|SPI|CAN|FDCAN)\w*HandleTypeDef\s+\w+)\s*[;=]', content)
                return [g.strip() for g in globs]
        except:
            return []
    
    def analyze(self):
        """Run full analysis"""
        self.scan_files()
        
        # Parse all files
        for folder in ['src', 'include']:
            for file in self.files[folder]:
                filename = file.name
                self.includes[filename] = self.parse_includes(file)
                self.functions[filename] = self.parse_functions(file)
                self.function_calls[filename] = self.parse_function_calls(file)
                self.globals[filename] = self.parse_globals(file)
                
    def categorize_file(self, filename):
        """Determine subsystem category"""
        name = filename.lower()
        if 'can' in name and 'message' in name:
            return 'can_msg'
        elif 'can' in name:
            return 'can'
        elif 'spi' in name or 'max' in name or 'asci' in name:
            return 'spi'
        elif 'adc' in name:
            return 'adc'
        elif 'led' in name:
            return 'led'
        elif 'log' in name or 'uart' in name:
            return 'log'
        elif 'error' in name:
            return 'error'
        elif 'init' in name or 'clock' in name:
            return 'init'
        elif 'main' in name:
            return 'main'
        else:
            return 'other'
            
    def generate_mermaid(self, output_file):
        """Generate detailed Mermaid flowchart with function-level details"""
        lines = [
            "```mermaid",
            "flowchart TB",
            ""
        ]
        
        # Track all nodes
        node_ids = {}
        node_counter = 0
        
        # Group files by category
        categories = defaultdict(list)
        for folder in ['src', 'include']:
            for file in self.files[folder]:
                cat = self.categorize_file(file.name)
                categories[cat].append(file.name)
        
        # Combine related categories
        combined = {
            'MAIN': ('🚀 MAIN', ['main']),
            'INIT': ('🔧 INIT', ['init']),
            'CAN_SYSTEM': ('� CAN SYSTEM', ['can', 'can_msg']),
            'SPI_SYSTEM': ('🔵 SPI SYSTEM', ['spi']),
            'ADC_SYSTEM': ('📊 ADC SYSTEM', ['adc']),
            'LED_SYSTEM': ('🟡 LED', ['led']),
            'LOG_SYSTEM': ('🟣 LOGGING', ['log']),
            'ERROR': ('🔴 ERROR', ['error']),
            'HAL': ('⚙️ HAL/SYSTEM', ['other'])
        }
        
        # Create detailed subgraphs
        for group_name, (label, cats) in combined.items():
            files_in_group = []
            for cat in cats:
                files_in_group.extend(categories.get(cat, []))
            
            if not files_in_group:
                continue
                
            lines.append(f"    subgraph {group_name}[{label}]")
            lines.append("        direction TB")
            
            for file in sorted(files_in_group):
                node_id = f"N{node_counter}"
                node_counter += 1
                node_ids[file] = node_id
                
                funcs = self.functions.get(file, [])
                
                # Show file with key functions
                if file.endswith('.c') and funcs:
                    # Show top functions
                    func_list = "<br/>".join(f"• {f}()" for f in funcs[:5])
                    if len(funcs) > 5:
                        func_list += f"<br/>• +{len(funcs)-5} more"
                    lines.append(f"        {node_id}[\"<b>{file}</b><br/>{func_list}\"]")
                elif file.endswith('.h'):
                    lines.append(f"        {node_id}[\"<b>{file}</b><br/>Interface\"]")
                else:
                    lines.append(f"        {node_id}[\"{file}\"]")
            
            lines.append("    end")
            lines.append("")
        
        lines.append("    %% ========== MAIN FLOW ==========")
        
        # Show main initialization sequence
        if 'main.c' in node_ids:
            main_id = node_ids['main.c']
            
            if 'init.c' in node_ids:
                lines.append(f"    {main_id} ===>|\"1. System_AppInit()\"| {node_ids['init.c']}")
            if 'adc.c' in node_ids:
                lines.append(f"    {main_id} ===>|\"2. ADC_App_Init()\"| {node_ids['adc.c']}")
            if 'spi.c' in node_ids:
                lines.append(f"    {main_id} ===>|\"3. SPI_App_Init()\"| {node_ids['spi.c']}")
            if 'can.c' in node_ids:
                lines.append(f"    {main_id} ===>|\"4. CAN_App_Init()\"| {node_ids['can.c']}")
            if 'led.c' in node_ids:
                lines.append(f"    {main_id} ===>|\"5. LED_All_Pulse()\"| {node_ids['led.c']}")
        
        lines.append("")
        lines.append("    %% ========== SERVICE TASKS ==========")
        
        # Show periodic service task calls
        if 'main.c' in node_ids:
            main_id = node_ids['main.c']
            
            if 'adc.c' in node_ids:
                lines.append(f"    {main_id} -->|\"Loop: ADC_ServiceTask()\"| {node_ids['adc.c']}")
            if 'spi.c' in node_ids:
                lines.append(f"    {main_id} -->|\"Loop: SPI_ServiceTask()\"| {node_ids['spi.c']}")
            if 'can.c' in node_ids:
                lines.append(f"    {main_id} -->|\"Loop: CAN_ServiceTask()\"| {node_ids['can.c']}")
        
        lines.append("")
        lines.append("    %% ========== CAN MESSAGE FLOW ==========")
        
        # CAN system internal flow
        if 'can.c' in node_ids and 'can_messages.c' in node_ids:
            lines.append(f"    {node_ids['can.c']} -->|\"Encode thermistor data<br/>CAN_Msg_EncodeThermJ1939Claim()\"| {node_ids['can_messages.c']}")
            lines.append(f"    {node_ids['can.c']} -->|\"Encode BMS broadcast<br/>CAN_Msg_EncodeThermBMSBroadcast()\"| {node_ids['can_messages.c']}")
            lines.append(f"    {node_ids['can.c']} -->|\"Encode cell voltage<br/>CAN_Msg_EncodeL180CellVoltage()\"| {node_ids['can_messages.c']}")
            lines.append(f"    {node_ids['can_messages.c']} -.->|\"Returns payload + ID\"| {node_ids['can.c']}")
            
        if 'can.c' in node_ids and 'can.h' in node_ids:
            lines.append(f"    {node_ids['can.h']} -.->|\"Declares API\"| {node_ids['can.c']}")
        if 'can_messages.h' in node_ids and 'can_messages.c' in node_ids:
            lines.append(f"    {node_ids['can_messages.h']} -.->|\"Defines structs\"| {node_ids['can_messages.c']}")
        
        lines.append("")
        lines.append("    %% ========== SPI/MAX17841B FLOW ==========")
        
        # SPI system internal flow
        if 'spi.c' in node_ids:
            spi_id = node_ids['spi.c']
            
            if 'spi_max.h' in node_ids:
                lines.append(f"    {spi_id} -->|\"SPI_Max_RequestCellFrame()<br/>Read battery cell voltages\"| {spi_id}")
            if 'max17841b.h' in node_ids:
                lines.append(f"    {node_ids['max17841b.h']} -.->|\"Register definitions<br/>RD_NXT_MSG, RD_RX_STATUS\"| {spi_id}")
            
            lines.append(f"    {spi_id} -->|\"ASCI_ReadNextMsg()<br/>Poll MAX17841B\"| {spi_id}")
        
        lines.append("")
        lines.append("    %% ========== CROSS-MODULE DEPENDENCIES ==========")
        
        # Logging usage
        if 'log.c' in node_ids:
            log_id = node_ids['log.c']
            for file in ['adc.c', 'spi.c', 'can.c', 'init.c']:
                if file in node_ids:
                    lines.append(f"    {node_ids[file]} -.->|\"LOG_INFO()\"| {log_id}")
        
        # LED usage
        if 'led.c' in node_ids:
            led_id = node_ids['led.c']
            for file in ['adc.c', 'spi.c', 'can.c']:
                if file in node_ids:
                    lines.append(f"    {node_ids[file]} -.->|\"LED control\"| {led_id}")
        
        # Error handling
        if 'error_handling.c' in node_ids:
            err_id = node_ids['error_handling.c']
            for file in ['adc.c', 'spi.c', 'can.c', 'init.c', 'log.c']:
                if file in node_ids:
                    lines.append(f"    {node_ids[file]} -.->|\"Error_Handler()\"| {err_id}")
        
        lines.append("")
        lines.append("    %% ========== TIMING INFO ==========")
        
        # Add timing info nodes
        lines.append("    TIMING[\"⏱️ TIMING<br/>ADC: 1s delay, 5s period<br/>SPI: 2s delay, 5s period<br/>CAN: 3s delay, 5s period\"]")
        lines.append("    style TIMING fill:#fff9c4,stroke:#f57f17,stroke-width:2px")
        
        lines.append("")
        lines.append("    %% ========== STYLING ==========")
        
        # Apply styles based on groups
        style_map = {
            'MAIN': 'mainStyle',
            'INIT': 'initStyle', 
            'CAN_SYSTEM': 'canStyle',
            'SPI_SYSTEM': 'spiStyle',
            'ADC_SYSTEM': 'adcStyle',
            'LED_SYSTEM': 'ledStyle',
            'LOG_SYSTEM': 'logStyle',
            'ERROR': 'errStyle',
            'HAL': 'otherStyle'
        }
        
        lines.append("    classDef mainStyle fill:#e3f2fd,stroke:#1976d2,stroke-width:4px")
        lines.append("    classDef initStyle fill:#f3e5f5,stroke:#7b1fa2,stroke-width:2px")
        lines.append("    classDef canStyle fill:#e8f5e9,stroke:#388e3c,stroke-width:3px")
        lines.append("    classDef spiStyle fill:#e1f5fe,stroke:#0277bd,stroke-width:3px")
        lines.append("    classDef adcStyle fill:#fff3e0,stroke:#f57c00,stroke-width:3px")
        lines.append("    classDef ledStyle fill:#fffde7,stroke:#f9a825,stroke-width:2px")
        lines.append("    classDef logStyle fill:#f3e5f5,stroke:#8e24aa,stroke-width:2px")
        lines.append("    classDef errStyle fill:#ffebee,stroke:#c62828,stroke-width:3px")
        lines.append("    classDef otherStyle fill:#eceff1,stroke:#546e7a,stroke-width:2px")
        
        lines.append("")
        
        # Apply class to nodes
        for group_name, (label, cats) in combined.items():
            files_in_group = []
            for cat in cats:
                files_in_group.extend(categories.get(cat, []))
            
            node_list = ",".join(node_ids[f] for f in files_in_group if f in node_ids)
            if node_list and group_name in style_map:
                lines.append(f"    class {node_list} {style_map[group_name]}")
        
        lines.append("```")
        
        # Write to file
        with open(output_file, 'w', encoding='utf-8') as f:
            f.write('\n'.join(lines))
        
        print(f"✅ Generated: {output_file}")
        print(f"📊 Files analyzed: {len(node_ids)}")
        print(f"⚡ Functions found: {sum(len(v) for v in self.functions.values())}")
        print(f"🔗 Detailed flow with function calls included")

if __name__ == "__main__":
    # Use current directory or specify path
    codebase_path = os.path.dirname(os.path.abspath(__file__))
    
    print("🔍 Analyzing codebase...")
    analyzer = CodebaseAnalyzer(codebase_path)
    analyzer.analyze()
    
    output_path = os.path.join(codebase_path, "docs", "auto_architecture.md")
    analyzer.generate_mermaid(output_path)
    
    print(f"\n📝 Open in VS Code: {output_path}")

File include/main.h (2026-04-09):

/*
 * ===========================================================================
 * File: main.h
 * Description: Project-wide hardware mappings and shared handles for main.c.
 *
 * Notes:
 *   - HAL and LL coexist intentionally; keep both includes available.
 * ===========================================================================
 */

/* Define to prevent recursive inclusion -------------------------------------*/
#ifndef __MAIN_H
#define __MAIN_H

#ifdef __cplusplus
extern "C" {
#endif

/* ----------------------- Includes ----------------------- */
#include "stm32g4xx_hal.h"
#include "error_handling.h"

/* Use LL alongside HAL: enabled from build system (platformio.ini -D) */
#ifdef USE_FULL_LL_DRIVER
#include "stm32g4xx_ll_rcc.h"
#include "stm32g4xx_ll_bus.h"
#include "stm32g4xx_ll_system.h"
#include "stm32g4xx_ll_exti.h"
#include "stm32g4xx_ll_cortex.h"
#include "stm32g4xx_ll_utils.h"
#include "stm32g4xx_ll_pwr.h"
#include "stm32g4xx_ll_gpio.h"
#endif /* USE_FULL_LL_DRIVER */

/* Explicitly include FDCAN HAL (pulled in via hal_conf when enabled) */
#include "stm32g4xx_hal_fdcan.h"

#if defined(USE_FULL_ASSERT)
#include "stm32_assert.h"
#endif

/* ----------------------- Exported types / externs ----------------------- */
extern FDCAN_HandleTypeDef    g_fdcan1;
extern FDCAN_TxHeaderTypeDef  g_can_tx_header;
extern uint8_t                g_can_tx_data[8];

/* Subsystem status flags - defined in main.c */
extern volatile bool log_status;
extern volatile bool can_status;
extern volatile bool therm_status;
extern volatile bool volt_status;

/* LED pins (adjust to match board wiring as needed) */
#define LED1_Pin          GPIO_PIN_9
#define LED1_GPIO_Port    GPIOA
#define LED2_Pin          GPIO_PIN_8
#define LED2_GPIO_Port    GPIOA
#define LED3_Pin          GPIO_PIN_9
#define LED3_GPIO_Port    GPIOC

/* ----------------------- Exported functions ----------------------- */
#ifdef __cplusplus
}
#endif

#endif /* __MAIN_H */

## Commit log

2026-03-26 pushed from school account
    [22.xlsx, MB1762-V3MINIE-B01.step, STLINK-V3MINIE-Box-V4.step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]
2026-03-26 deleted unncessary
    [22.xlsx, MB1762-V3MINIE-B01.step, STLINK-V3MINIE-Box-V4.step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]
2026-03-26 fixed transfer issues
    [22.xlsx, MB1762-V3MINIE-B01.step, STLINK-V3MINIE-Box-V4.step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]
2026-03-28 added dual module testing and fixes
    [can_debugging.c, can_messages.c, can_messages.h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]
2026-03-31 IT FINALLY WORKS, able to read voltage taps using BQ79616 chip
    [bq79616.obj, dabort.obj, esm.obj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]
2026-03-31 added changes to fix and make it better
    [bq79616.c]
2026-03-31 fixed fault 20 flag from CRC Check
    [bq79616.c, bq79616.h]
2026-04-09 updated UART and status variables
2026-04-09 just tested BQ ADC still works despite all changes
2026-04-09 Replace main with local version
    [bq79616.obj, dabort.obj, esm.obj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]
2026-04-09 Updated subsystems to use status vars (defined in main) to ensure each subsystem can run independently even if other subsystems fail
    [bq79616.obj, dabort.obj, esm.obj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]
2026-04-10 Renamed references to internal ADC (STM32) to Thermistor Values, Renamed refenreces to external ADC (BQ chip) as voltage taps
2026-04-12 changed service routine from polling to interrupt
2026-04-12 reverted CAN service routine to polling instead of interrupt based to error test
    [can.c]
2026-04-13 changed CAN service routine back to use interrupt instead of polling
2026-04-13 Updated Thermistor Logging and sampling to use new dynamic therm structure
2026-04-14 fix: timing issue resolved no dropped packets
    [bq79616.c, can.c, can_debugging.c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]
2026-04-14 feat: external ADC pushed to CAN messages
2026-04-14 fix: change in the timing of a fault message
    [can_messages.c]
2026-04-15 Updated LEDs to be associated with each individual subsystem
2026-04-15 remove non-cached therm log because that function is WRONG
    [therm.c]
2026-04-15 fix: deleted all of old logging
    [therm.c, therm.h]
2026-04-16 feat: added fault testing and redit formatting of BQ ADC output
2026-04-16 Updated logging functions to be more readable; Added Init Log to print status for all subsystems
2026-04-17 fix: changed colors for logging
    [bq79616.obj, dabort.obj, esm.obj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]
2026-04-17 feat: because of iso ground fault added fix to vtap 1 & 14
    [bq79616.c]
2026-04-17 kayla updated logs and fixed bq reported voltage for first and last tap (use iso ground, leading to an unexpected 1v difference from true reading)
    [bq79616.obj, dabort.obj, esm.obj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]
2026-04-22 pushing before branch reset, bq seems to never work properly???
    [bq79616.c, bq79616.h, init.c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]
2026-06-03 Switch main build target to STM32G474RB and clean tracked temp files
